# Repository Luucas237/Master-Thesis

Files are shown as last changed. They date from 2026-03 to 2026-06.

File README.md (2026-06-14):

**SSH Login:**
* Command: `ssh lukasgrab@raspberrypi.local`
* Password: `Rasbian1234`
* ip: `192.168.0.43`

```bash
xhost +local:root

docker run -it --rm --net=host --device /dev/snd -e DISPLAY=$DISPLAY -v /tmp/.X11-unix:/tmp/.X11-unix -v ~/Robotyka/Master-Thesis/Color_detection_ros_Ubuntu:/workspace -w /workspace master_pan_tilt_env bash

colcon build --packages-select pan_tilt_description --symlink-install

source install/setup.bash

ros2 run pan_tilt_description turret_gui.py
```

## ===== Launching =====
**Rasbian**
```bash
while true; do rpicam-vid -n -t 0 --width 640 --height 480 --framerate 30 --codec mjpeg --listen -o tcp://0.0.0.0:5000; sleep 1; done

rpicam-vid -t 0 --width 640 --height 480 --framerate 30 --codec mjpeg --inline -o udp://192.168.0.255:5000
```
**Rasbian ssh ubuntu**
```bash
cd /home/lukasgrab/Turret
libcamerify python3 tracker_guiless.py
python3 esp_test.py
python3 tracker.py
```
**Ubuntu**
```bash
mpv tcp://192.168.0.43:5000 --profile=low-latency --untimed --demuxer=lavf --demuxer-lavf-format=mjpeg
```

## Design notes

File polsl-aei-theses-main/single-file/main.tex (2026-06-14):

% !TeX spellcheck = pl_PL
%%%%%%%%%%%%%%%%%%%%%%%%%%%%%%%%%%%%%%%%%%%
%                                        %
% Szablon pracy dyplomowej magisterskiej %
% zgodny  z aktualnymi  przepisami  SZJK %
%                                        %
%%%%%%%%%%%%%%%%%%%%%%%%%%%%%%%%%%%%%%%%%%
%                                        %
%  (c) Krzysztof Simiński, 2018-2023     %
%                                        %
%%%%%%%%%%%%%%%%%%%%%%%%%%%%%%%%%%%%%%%%%%
%                                        %
% Najnowsza wersja szablonów jest        %
% podstępna pod adresem                  %
% github.com/ksiminski/polsl-aei-theses  %
%                                        %
%%%%%%%%%%%%%%%%%%%%%%%%%%%%%%%%%%%%%%%%%%
%
%
% Projekt LaTeXowy zapewnia odpowiednie formatowanie pracy,
% zgodnie z wymaganiami Systemu zapewniania jakości kształcenia.
% Proszę nie zmieniać ustawień formatowania (np. fontu,
% marginesów, wytłuszczeń, kursywy itd. ).
%
% Projekt można kompilować na kilka sposobów.
%
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
% brak kapitalizacji zywej paginy
\usepackage{fancyhdr}
\pagestyle{fancy}
\fancyhf{}
\fancyhead[LO]{\nouppercase{\it\rightmark}}
\fancyhead[RE]{\nouppercase{\it\leftmark}}
\fancyhead[LE,RO]{\it\thepage}

\fancypagestyle{tylkoNumeryStron}{%
   \fancyhf{} 
   \fancyhead[LE,RO]{\it\thepage}
}

\fancypagestyle{bezNumeracji}{%
   \fancyhf{} 
   \fancyhead[LE,RO]{}
}

\fancypagestyle{NumeryStronNazwyRozdzialow}{%
   \fancyhf{} 
   \fancyhead[LE]{\nouppercase{\autor}}
   \fancyhead[RO]{\nouppercase{\leftmark}} 
   \fancyfoot[CE, CO]{\thepage}
}

%%%%%%%%%%%%% OBCE WTRETY  
\newcommand{\obcy}[1]{\emph{#1}}
\newcommand{\english}[1]{{\selectlanguage{british}\obcy{#1}}}
%%%%%%%%%%%%%%%%%%%%%%%%%%%%%

% polskie oznaczenia funkcji matematycznych
\renewcommand{\tan}{\operatorname {tg}}
\renewcommand{\log}{\operatorname {lg}}

% jeszcze jakies drobiazgi

\newcounter{stronyPozaNumeracja}

%%%%%%%%%%%%%%%%%%%%%%%%%%% 
\newcommand{\printOpiekun}[1]{%		

    \StrLen{\Consultant}[\mystringlen]
    \ifthenelse{\mystringlen > 0}%
    {%
       {\large{\bfseries OPIEKUN, PROMOTOR POMOCNICZY}\par}
       
       {\large{\bfseries \Consultant}\par}
    }%
    {}
} 
%
%%%%%%%%%%%%%%%%%%%%%%%%%%%%%%%%%%%%%%%%%%%%%%
 
% Proszę nie modyfikować poniższych definicji!
\newcommand{\Author}{\FirstNameAuthor\ \MakeUppercase{\SurnameAuthor}} 
\newcommand{\Coauthor}{\FirstNameCoauthor\ \MakeUppercase{\SurnameCoauthor}}
\newcommand{\Type}{PRACA MAGISTERSKA}
\newcommand{\Faculty}{Wydział Automatyki, Elektroniki i Informatyki} 
\newcommand{\Polsl}{Politechnika Śląska}
\newcommand{\Logo}{politechnika_sl_logo_bw_pion_pl.pdf}
\newcommand{\LeftId}{Nr albumu}
\newcommand{\LeftProgram}{Kierunek}
\newcommand{\LeftSpecialisation}{Specjalność}
\newcommand{\LeftSUPERVISOR}{PROWADZĄCY PRACĘ}
\newcommand{\LeftDEPARTMENT}{KATEDRA}
%%%%%%%%%%%%%%%%%%%%%%%%%%%%%%%%%%%%%%%%%%%%%%

%%%%%%%%%%%%%%%%%%%%%%%%%%%%%%%%%%%%%%%%%%%%%%%
%                                             %
% KONIEC USTAWIEŃ                             %
%                                             %
%%%%%%%%%%%%%%%%%%%%%%%%%%%%%%%%%%%%%%%%%%%%%%%

%%%%%%%%%%%%%%%%%%%%%%%%%%%%%%%%%%%%%%%%%%%%%%%
%                                             %
% MOJE PAKIETY, USTAWIENIA ITD                %
%                                             %
%%%%%%%%%%%%%%%%%%%%%%%%%%%%%%%%%%%%%%%%%%%%%%%

% Tutaj proszę umieszczać swoje pakiety, makra, ustawienia itd.

%%%%%%%%%%%%%%%%%%%%%%%%%%%%%%%%%%%%%%%%%%%%%%%%%%%%%%%%%%%%%%%%%%%%%
% listingi i fragmentu kodu źródłowego 
% pakiet: listings lub minted
% % % % % % % % % % % % % % % % % % % % % % % % % % % % % % % % % % % 

% biblioteka listings
\usepackage{listings}
\lstset{%
morekeywords={string,exception,std,vector},% słowa kluczowe rozpoznawane przez pakiet listings
language=C++,% C, Matlab, Python, SQL, TeX, XML, bash, ... – vide https://www.ctan.org/pkg/listings
commentstyle=\textit,%
identifierstyle=\textsf,%
keywordstyle=\sffamily\bfseries, %\texttt, %
%captionpos=b,%
tabsize=3,%
frame=lines,%
numbers=left,%
numberstyle=\tiny,%
numbersep=5pt,%
breaklines=true,%
escapeinside={@*}{*@},%
}

% % % % % % % % % % % % % % % % % % % % % % % % % % % % % % % % % % % 
% pakiet minted
%\usepackage{minted}

% pakiet wymaga specjalnego kompilowania:
% pdflatex -shell-escape main.tex
% xelatex  -shell-escape main.tex

%\usepackage[chapter]{minted} % [section]
%%\usemintedstyle{bw}   % czarno-białe kody 
%
%\setminted % https://ctan.org/pkg/minted
%{
%%fontsize=\normalsize,%\footnotesize,
%%captionpos=b,%
%tabsize=3,%
%frame=lines,%
%framesep=2mm,
%numbers=left,%
%numbersep=5pt,%
%breaklines=true,%
%escapeinside=@@,%
%}

%%%%%%%%%%%%%%%%%%%%%%%%%%%%%%%%%%%%%%%%%%%%%%%%%%%%%%%%%%%%%%%%%%%%%

%%%%%%%%%%%%%%%%%%%%%%%%%%%%%%%%%%%%%%%%%%%%%%%
%                                             %
% KONIEC MOICH USTAWIEŃ                       %
%                                             %
%%%%%%%%%%%%%%%%%%%%%%%%%%%%%%%%%%%%%%%%%%%%%%%

%%%%%%%%%%%%%%%%%%%%%%%%%%%%%%%%%%%%%%%%

\begin{document}
%\kslistofremarks

\frontmatter

%%%%%%%%%%%%%%%%%%%%%%%%%%%%%%%%%%%%%%%%%%%%%%%
%                                             %
% PROSZĘ NIE MODYFIKOWAĆ STRONY TYTUŁOWEJ!    %
%                                             %
%%%%%%%%%%%%%%%%%%%%%%%%%%%%%%%%%%%%%%%%%%%%%%%

%%%%%%%%%%%%%%%%%%  STRONA TYTUŁOWA %%%%%%%%%%%%%%%%%%%
\pagestyle{empty}
{
	\newgeometry{top=1.5cm,%
	             bottom=2.5cm,%
	             left=3cm,
	             right=2.5cm}
 
	\ifxetex 
	  \begingroup
	  \setsansfont{Calibri}
	   
	\fi 
	 \sffamily
	\begin{center}
	

	{\Large\bfseries\Type\par}
	
	\vfill  \vfill  
			 
	{\large\Title\par}
	
	\vfill  
		
	{\large\bfseries\Author\par}
	
	{\normalsize\bfseries \LeftId: \IdAuthor}

	\printCoauthor
	
	\vfill  		
 
	{\large{\bfseries \LeftProgram:} \Program\par} 
	
	{\large{\bfseries \LeftSpecialisation:} \Specialisation\par} 
	 		
	\vfill  \vfill 	\vfill 	\vfill 	\vfill 	\vfill 	\vfill  
	 
	{\large{\bfseries \LeftSUPERVISOR}\par}
	
	{\large{\bfseries \Supervisor}\par}
				
	{\large{\bfseries \LeftDEPARTMENT\ \Departament} \par}
		
	{\large{\bfseries \Faculty}\par}
		
	\vfill  \vfill  

    \printOpiekun{\Consultant}
    
	\vfill  \vfill  
		
    {\large\bfseries  Gliwice \the\year}

   \end{center}	
       \ifxetex 
       	  \endgroup
       \fi
	\restoregeometry
}
  
%%%%%%%%%%%%%%%%%%%%%%%%%%%%%%%%%%%%%%%%%%%%%%%
%                                             %
% KONIEC STRONY TYTUŁOWEJ                     %
%                                             %
%%%%%%%%%%%%%%%%%%%%%%%%%%%%%%%%%%%%%%%%%%%%%%%  

\cleardoublepage

\rmfamily\normalfont
\pagestyle{empty}

%%% No to zaczynamy pisać pracę :-) %%%%

% TODO
\subsubsection*{Tytuł pracy} 
\Title

\subsubsection*{Streszczenie}

Przedmiotem niniejszej pracy magisterskiej jest projekt oraz wykonanie zrobotyzowanego demonstratora systemu kierowania niskomocowym laserem, zdolnego do automatycznego śledzenia poruszającego się celu na podstawie obrazu rejestrowanego przez kamerę cyfrową. Zasadniczą część badań stanowiła synteza i optymalizacja algorytmów sterowania nadążnego, umożliwiających precyzyjne utrzymanie wiązki optycznej na dedykowanym markerze. W pracy szczegółowo opisano architekturę rozproszoną zaprojektowanego systemu, obejmującą jednostkę nadrzędną do przetwarzania wizji (mikrokomputer Raspberry Pi) oraz warstwę wykonawczą realizującą wysterowanie silników krokowych (mikrokontroler ESP32). Dokonano komparatywnego zestawienia klasycznego algorytmu ciągłego (regulator PID strojony analitycznie metodą CHR oraz heurystycznie) z nieliniowym sterowaniem przekaźnikowym (regulator trójstawny \textit{Bang-Off-Bang}). Przedstawiono również proces parametryzacji układu oraz zaimplementowane techniki poprawy jakości i stabilności śledzenia, w tym dyskretny filtr Kalmana kompensujący zjawisko okluzji. Integralną część pracy stanowi obszerny zestaw badań laboratoryjnych oraz poligonowych (z wykorzystaniem drona), w których zweryfikowano algorytmy pod kątem precyzji naprowadzania (błąd średniokwadratowy, maksymalny uchyb dynamiczny) i kultury pracy mechaniki w zróżnicowanych warunkach i dystansach. Praca stanowi kompleksowe studium projektowania wieloosiowych, optoelektronicznych systemów śledzenia na wbudowanych platformach sprzętowych.

\subsubsection*{Słowa kluczowe} 
Laser niskomocowy, BSP, system śledzenia, PID, Trójpozycyjna regulacja.

\newpage
\subsubsection*{Thesis title} 
\begin{otherlanguage}{british}
\TitleAlt
\end{otherlanguage}

\subsubsection*{Abstract} 
\begin{otherlanguage}{british}
The subject of this Master's thesis is the design and implementation of a robotic demonstrator for a low-power laser targeting system, capable of automatically tracking a moving target based on images captured by a digital camera. The core of the research involved the synthesis and optimization of tracking control algorithms, enabling the precise maintenance of the optical beam on a dedicated marker. This thesis details the distributed architecture of the designed system, comprising a master unit for vision processing (a Raspberry Pi microcomputer) and an execution layer responsible for driving stepper motors (an ESP32 microcontroller). A comparative analysis was conducted between a classical continuous algorithm (a PID controller tuned analytically using the CHR method as well as heuristically) and nonlinear relay control (a three-position \textit{Bang-Off-Bang} controller). The parameterization process of the system was also presented, along with implemented techniques for improving tracking quality and stability, including a discrete Kalman filter compensating for the occlusion phenomenon. An integral part of the thesis consists of an extensive set of laboratory and field tests (involving a drone), wherein the algorithms were verified in terms of targeting precision (Root Mean Square Error, peak dynamic error) and the smoothness of mechanical operation across diverse conditions and distances. This thesis provides a comprehensive study on the design of multi-axis, optoelectronic tracking systems on embedded hardware platforms.

\end{otherlanguage}
\subsubsection*{Key words}  
\begin{otherlanguage}{british}
Low-power laser, UAV, tracking system, PID, Bang-off-bang regulation.
\end{otherlanguage}

%%%%%%%%%%%%%%%%%% SPIS TRESCI %%%%%%%%%%%%%%%%%%%%%%
% Add \thispagestyle{empty} to the toc file (main.toc), because \pagestyle{empty} doesn't work if the TOC has multiple pages
\addtocontents{toc}{\protect\thispagestyle{empty}}
\tableofcontents

%%%%%%%%%%%%%%%%%%%%%%%%%%%%%%%%%%%%%%%%%%%%%%%%%%%%%
\setcounter{stronyPozaNumeracja}{\value{page}}
\mainmatter
\pagestyle{empty}

\cleardoublepage

\pagestyle{NumeryStronNazwyRozdzialow}

%%%%%%%%%%%%%% wlasciwa tresc pracy %%%%%%%%%%%%%%%%%

% TODO
\chapter{Wstęp}

%\begin{itemize}
%\item wprowadzenie w problem/zagadnienie 
%\item osadzenie problemu w dziedzinie 
%\item cel pracy 
%\item zakres pracy 
%\item zwięzła charakterystyka rozdziałów 
%\end{itemize}

\section{Wprowadzenie do problematyki systemów antydronowych}

Współczesne środowisko bezpieczeństwa cywilnego oraz militarnego narażone jest na rosnące zagrożenia związane z rozwojem technologii bezzałogowych statków powietrznych. Zwiększająca się dostępność niewielkich i tanich dronów wpłynęła na wzrost przestępczości w kontekście naruszania prywatności oraz zakłócania funkcjonowania infrastruktury krytycznej. Dodatkowo, ostatnie lata pokazały, że mogą być one wykorzystywane jako precyzyjny środek rażenia celów wrażliwych w konfliktach zbrojnych. Niskobudżetowe modyfikacje komercyjnych dronów sprawiają, że są one realnym zagrożeniem dla obiektów o znacznie wyższej wartości.

W odpowiedzi na to wyzwanie testowane są systemy wykorzystujące wysokoenergetyczne wiązki laserowe, które postrzegane są jako optymalne rozwiązanie problemu asymetrii kosztów. W przeciwieństwie do konwencjonalnych systemów rakietowych czy artyleryjskich, gdzie koszt pojedynczego efektora może wynosić dziesiątki tysięcy dolarów, system laserowy oferuje możliwość oddania strzału za kwotę wynikającą jedynie z zużycia energii elektrycznej. Warto zaznaczyć, że wiązka lasera poruszająca się z prędkością światła eliminuje konieczność obliczania wyprzedzenia balistycznego, co teoretycznie upraszcza proces celowania. Jednakże implementacja napotyka na szereg barier inżynierskich m.in. odpowiednia regulacja mocy źródła promieniowania, optymalizacja detekcji w czasie rzeczywistym oraz mechaniczna precyzja układu kierowania wiązką. Ponadto należy mieć na uwadze, że ze względu na znacznie wyższą moc rażenia i wydłużony zasięg operacyjny współczesnych emiterów, jakakolwiek usterka sprzętowa lub błąd algorytmu niesie ze sobą krytyczne zagrożenie. Ewentualna utrata kontroli nad zrobotyzowaną głowicą nadążną może skutkować przypadkowym skierowaniem niszczącej wiązki na osoby postronne, co bezwzględnie wymusza implementację rygorystycznych, wielopoziomowych protokołów bezpieczeństwa.

Systemy klasy ATP, odpowiedzialne za akwizycję, śledzenie i wskazywanie celu, stanowią serce każdego urządzenia neutralizującego. Ich zadaniem jest utrzymanie skupionej plamki lasera na wrażliwym elemencie szybko poruszającego się obiektu przez czas niezbędny do jego termicznego uszkodzenia. O ile w systemach stacjonarnych dalekiego zasięgu problem ten rozwiązuje się poprzez masywne, stabilizowane żyroskopowo podstawy i kosztowne napędy bezpośrednie, o tyle w segmencie rozwiązań mobilnych i niskokosztowych wciąż brakuje skutecznych architektur. Niniejsza praca podejmuje próbę wypełnienia tej luki poprzez opracowanie zminiaturyzowanego systemu śledzącego, który integruje algorytmy przetwarzania obrazu w czasie rzeczywistym na niskobudżetowej platformie obliczeniowej wraz z możliwością działania na zewnętrznym źródle zasilania. Projekt ten ma na celu nie tylko demonstrację technologii, ale również zbadanie istotnych zagadnień inżynierskich m.in. opóźnienia w pętli sprzężenia zwrotnego, wpływ wybranych metod regulacji na stabilność układu czy mechaniczne aspekty przeniesienia napędu. Zwieńczeniem prac jest stworzenie funkcjonalnego prototypu, który posłuży jako baza do dalszych badań i rozwoju w dziedzinie systemów antydronowych.

% Współczesne środowisko bezpieczeństwa, podlega dynamicznym przemianom wymuszonym przez gwałtowny rozwój technologii bezzałogowych. Powszechna dostępność bezzałogowych statków powietrznych, potocznie określanych mianem dronów, doprowadziła do powstania nowych kategorii zagrożeń, z którymi tradycyjne systemy ochrony nie potrafią efektywnie rywalizować. Niewielkie, tanie i trudne do wykrycia platformy latające mogą być wykorzystywane nie tylko do naruszania prywatności czy zakłócania funkcjonowania infrastruktury krytycznej, takiej jak porty lotnicze, ale również jako precyzyjne środki rażenia w konfliktach. Obserwowane w ostatnich latach konflikty zbrojne jednoznacznie wykazały, że komercyjne drony, po niewielkich modyfikacjach, stają się skuteczną bronią, zdolną do unieszkodliwiania celów o wartości wielokrotnie przewyższającej koszt samego bezzałogowca. Zjawisko to zdefiniowało pilną potrzebę opracowania nowych metod neutralizacji, które byłyby ekonomicznie uzasadnione i technicznie skuteczne przeciwko masowym atakom małych obiektów latających.

% W odpowiedzi na to wyzwanie inżynieria systemów obronnych intensywnie rozwija koncepcję broni skierowanej energii. Systemy wykorzystujące wysokoenergetyczne wiązki laserowe postrzegane są jako optymalne rozwiązanie problemu asymetrii kosztów. W przeciwieństwie do konwencjonalnych systemów rakietowych czy artyleryjskich, gdzie koszt pojedynczego efektora może wynosić dziesiątki tysięcy dolarów, system laserowy oferuje możliwość oddania strzału za kwotę wynikającą jedynie z zużycia energii elektrycznej. Co więcej, wiązka lasera poruszająca się z prędkością światła eliminuje konieczność obliczania wyprzedzenia balistycznego, co teoretycznie upraszcza proces celowania. Jednakże praktyczna implementacja tej technologii napotyka na szereg barier inżynierskich, z których najpoważniejszą nie jest obecnie sama moc źródła promieniowania, lecz precyzja i szybkość działania systemu kierowania wiązką.

\section{Identyfikacja problemów badawczych}

Zadanie te wiąże się z koniecznością rozwiązania złożonych problemów interdyscyplinarnych, obejmujących mechanikę, optoelektronikę oraz informatykę. 

Pierwszym i kluczowym wyzwaniem jest opóźnienie w pętli sprzężenia zwrotnego układu sterowania. W systemach wizyjnych proces ten obejmuje akwizycję klatki obrazu, jej przesył do jednostki obliczeniowej, detekcję obiektu, wyznaczenie uchybu regulacji oraz wysterowanie napędów. Każdy z tych etapów wprowadza pewną zwłokę czasową. W przypadku śledzenia obiektów statycznych opóźnienie to jest pomijalne, jednak przy obiektach o wysokiej dynamice, takich jak drony wykonujące manewry unikowe, staje się ono przyczyną niestabilności układu. Liniowy sposób odczytu matrycy powoduje, że szybko poruszające się obiekty ulegają deformacjom geometrycznym, co drastycznie obniża skuteczność algorytmów detekcji opartych na uczeniu maszynowym.

Drugim istotnym problemem jest jakość układu mechanicznego napędu. Precyzyjne celowanie wymaga mechanizmu o wysokiej sztywności i zerowym luzie zwrotnym. Tradycyjne przekładnie zębate, powszechnie stosowane w serwomechanizmach modelarskich, charakteryzują się luzem technologicznym niezbędnym do ich pracy, który jednak przy zmianie kierunku obrotu powoduje chwilowy brak reakcji układu wyjściowego. W systemie śledzącym, który nieustannie koryguje położenie w osiach azymutu i elewacji, zjawisko to uniemożliwia płynne podążanie za celem, wprowadzając drgania mechaniczne przenoszone na wiązkę lasera. 

Trzecim aspektem jest interakcja promieniowania laserowego z materiałem celu. Większości systemów wzmacniane są włóknem węglowym jako głównym budulecem ram dronów i wykazują one specyficzne właściwości absorpcyjne. Istnieje zatem potrzeba zbadania efektywności źródeł promieniowania, które są w stanie wytworzyć wystarczającą ilość ciepła do uszkodzenia struktury kompozytowej.

\section{Cel i zakres pracy}

Głównym celem niniejszej pracy jest zaprojektowanie, wykonanie oraz weryfikacja eksperymentalna autonomicznego systemu mechatronicznego dwuosiowego, przeznaczonego do wykrywania, śledzenia i symulowanej neutralizacji dynamicznych celów powietrznych.

Zakres pracy obejmuje pełny proces inżynierski, począwszy od analizy teoretycznej, poprzez projektowanie CAD i dobór komponentów elektronicznych, aż po implementację oprogramowania i testy poligonowe. W warstwie mechanicznej praca koncentruje się na opracowaniu przekładni o uzębieniu strzałkowym mających na celu eliminację luzów zwrotnych. W warstwie informatycznej kluczowym elementem jest implementacja systemu wizyjnego bazującego na algorytmach segmentacji barw, wspieranych predykcyjną estymacją kinematyki obiektu za pomocą filtru Kalmana. Warstwa wykonawcza obejmuje integrację modułu lasera półprzewodnikowego dużej mocy oraz systemu bezpiecznego sterowania wiązką.

\section{Układ pracy}

Struktura niniejszej pracy przedstawia ewolucję zaprojektowanego systemu w kierunku realizacji postawionych celów orazetapy procesu badawczego.
Treść została podzielona na sześć zasadniczych rozdziałów.

Rozdział drugi stanowi przegląd literatury dotyczącej współczesnych metod śledzenia obiektów oraz teorii sterowania układami inercyjnymi. Zawiera również analizę dostępnych technologii laserowych w kontekście systemów celowniczych oraz ocenę ich skuteczności na podstawie doniesień naukowych.

Rozdział trzeci opisuje proces projektowania i budowy sprzętowej części demonstratora. Skoncentrowano się w nim na mechanice dwuosiowej platformy obrotowej. Przedstawiono tu również schemat architektury elektronicznej, bazującej na integracji platformy komputerowej Raspberry Pi z mikrokontrolerem ESP32 wraz z modułem laserowym i dystrybucją zasilania.

Rozdział czwarty poświęcony jest szczegółowemu opisowi zaimplementowanych algorytmów detekcji i przetwarzania obrazu. Omówiono w nim architekturę systemu wizyjnego i symulacyjnego opartego na ROS2. Opisano adaptację do dynamiki sceny, wykorzystując algorytmy detekcji ruchu na statycznym tle oraz progowanie w przestrzeni barw (HSV). W tej części pracy przedstawiono również matematyczny model filtru Kalmana, wdrożony w celu predykcji trajektorii celu i kompensacji chwilowej utraty widoczności.

Rozdział piąty koncentruje się na analizie dynamiki obiektu i syntezie praw sterowania. Przeprowadzono w nim identyfikację modelu kinematycznego na podstawie odpowiedzi skokowej w otwartej pętli, uwzględniając opóźnienia transportowe oraz inercję mechaniki. Główną część rozdziału stanowi analityczne strojenie dwóch układów sterowania: zoptymalizowanego regulatora trójstawnego (\textit{Bang-Off-Bang}) z wyliczoną strefą nieczułości oraz ciągłego regulatora proporcjonalno-różniczkującego, opartego na metodzie Chien-Hrones-Reswick.

Rozdział szósty prezentuje metodykę oraz wyniki badań eksperymentalnych zaprojektowanej głowicy nadążnej. Zawiera on kompleksowe porównanie obu zaimplementowanych algorytmów sterowania w odpowiedzi na wymuszenia skokowe, krzywoliniowe oraz podczas dynamicznej zmiany odległości. Przedstawiono w nim również ocenę skuteczności demonstratora w trudnych warunkach polowych podczas śledzenia poruszającego się bezzałogowego statku powietrznego.

Pracę zamyka podsumowanie, w którym zawarto krytyczną ocenę stopnia realizacji postawionych celów, omówiono napotkane trudności sprzętowo-środowiskowe oraz sformułowano szczegółowe rekomendacje i perspektywy dalszego rozwoju zrobotyzowanych systemów obronnych.

% TODO
\chapter{Analiza tematu}  % Analiza tematu
% 

%\begin{itemize}
%\item Jaki problem chcę (muszę :-) rozwiązać?
%\item Dlaczego rozwiązanie problemu jest ważne?
%\item Jak inni rozwiązują ten problem?
%\item Jakie są zalety i wady tych rozwiązań?
%\end{itemize}

\section{Specyfika procesu neutralizacji kinetycznej i energetycznej}

Zadanie polegające na wykryciu, śledzeniu i neutralizacji niewielkiego, szybko poruszającego się obiektu w przestrzeni powietrznej stanowi złożone wyzwanie. Cel, taki jak dron wyścigowy FPV czy amunicja krążąca, charakteryzuje się wysoką dynamiką zmian wektora prędkości, co w połączeniu z nieprzewidywalnymi zakłóceniami zewnętrznymi, wymaga od układu sterowania reakcji w czasie zbliżonym do rzeczywistego.

Istotą problemu jest zamknięcie pętli sprzężenia zwrotnego w układzie wizyjnym. Proces ten składa się z sekwencji zdarzeń obejmującej akwizycję fotonów przez matrycę światłoczułą, cyfrowy odczyt i transmisję danych, algorytmiczną detekcję obiektu, estymację błędu położenia oraz mechaniczną reakcję napędu. Sumaryczny czas trwania tych operacji definiuje opóźnienie systemowe. W systemach śledzących, opóźnienie to wprowadza przesunięcie fazowe w sygnale sterującym. W praktyce oznacza to, że jeśli system reaguje zbyt wolno w stosunku do prędkości kątowej celu, wiązka lasera nie tylko nie trafi w obiekt, ale cały układ mechaniczny może wpaść w oscylacje o narastającej amplitudzie. Wyzwanie to jest potęgowane przez konieczność utrzymania skupionej plamki lasera na powierzchni celu przez czas niezbędny do przekazania niszczącej dawki energii termicznej.

\newpage

\section{Przegląd dostępnych rozwiązań i ich ograniczenia}

Analiza rynku systemów antydronowych pozwala na wyodrębnienie dwóch skrajnych podejść do rozwiązania problemu śledzenia, z których żadne nie spełnia w pełni założeń projektowych dla taniego i mobilnego systemu ochrony.

Pierwszą grupę stanowią profesjonalne systemy militarne klasy CIWS (ang. \textit{Close-In Weapon Systems}). Rozwiązania te wykorzystują aktywne radary śledzące oraz głowice optoelektroniczne. Napęd realizowany jest zazwyczaj poprzez silniki momentowe w układzie bezpośrednim, co eliminuje luzy mechaniczne i zapewnia dynamikę niezbędną do śledzenia obiektów naddźwiękowych. Mimo wysokiej skuteczności, bariera kosztowa oraz masa własna tych urządzeń wykluczają ich powszechne zastosowanie do ochrony infrastruktury cywilnej czy wykorzystanie w systemach przenośnych.

Na przeciwległym biegunie znajdują się rozwiązania amatorskie i półprofesjonalne, bazujące na podzespołach modelarskich. Konstrukcje te wykorzystują zazwyczaj serwomechanizmy sterowane sygnałem PWM oraz tanie kamery internetowe lub przemysłowe standardu USB. Głównym ograniczeniem tych systemów jest niska sztywność mechaniczna oraz obecność znaczących luzów w przekładniach zębatych serwomechanizmów. Luz zwrotny powoduje powstanie strefy nieczułości przy zmianie kierunku obrotu głowicy, co uniemożliwia precyzyjne mikrokorekty położenia wiązki lasera. Ponadto, budżetowe systemy wizyjne w przeważającej większości korzystają z sensorów CMOS wyposażonych w migawkę postępującą. Przy dużej prędkości obrotowej głowicy, liniowy sposób odczytu matrycy powoduje geometryczne zniekształcenia obrazu, co wprowadza błędne dane do algorytmów predykcji ruchu i często prowadzi do całkowitej rozbieżności modelu śledzenia.

\section{Zidentyfikowane bariery technologiczne}

Pierwszą barierą jest problem mechaniczny związany z precyzją przekładni. Wymóg niskiego kosztu i małej masy sugeruje wykorzystanie technologii druku 3D, jednak standardowe tworzywa termoplastyczne charakteryzują się mniejszą sztywnością niż metal. Konieczne jest zatem zaprojektowanie takiej geometrii uzębienia, która zapewni samocentrowanie układu, minimalizację luzów oraz równomierny rozkład naprężeń, co jest trudne do osiągnięcia przy użyciu typowych zębów prostych.

Drugą barierą jest wydajność obliczeniowa w kontekście opóźnień. Zastosowanie zaawansowanych sieci neuronowych do detekcji dronów na platformach wbudowanych wiąże się ze znacznym obciążeniem procesora i spadkiem liczby klatek na sekundę. Wymaga to implementacji hybrydowych algorytmów sterowania, które potrafią estymować pozycję celu w chwilach braku nowych danych wizyjnych.

Trzecią barierą jest efektywność energetyczna procesu neutralizacji. Typowe dla dronów komercyjnych materiały konstrukcyjne, takie jak polimery wzmacniane włóknem węglowym, wykazują zróżnicowaną absorpcję promieniowania. Wykorzystanie standardowych laserów często wymaga stosowania wysokich mocy, co komplikuje układ zasilania i chłodzenia. 

Poniższa analiza literatury szczegółowo omawia stan wiedzy w zakresie metod kompensacji tych ograniczeń, stanowiąc teoretyczną podbudowę dla rozwiązań zaproponowanych w dalszej części pracy.

%%%%%%%%%%%%%%%% LITERATURA %%%%%%%%%%%%%%%%
\section{Analiza literatury}

\subsection{Metody śledzenia obiektów}

W pracy Li i in. \cite{bib:Li2025} przeprowadzono szczegółową analizę wpływu sprzężenia zwrotnego z obrazu na dynamikę systemu \textbf{ATP (Acquisition, Tracking, Pointing)}. System tego typu można traktować jako układ serwomechanizmu, w którym sterowanie odbywa się na podstawie sygnału z kamery. W literaturze wyróżnia się dwa główne problemy ograniczające możliwości precyzyjnego śledzenia. Pierwszym z nich jest \textbf{opóźnienie obrazu} (np. rzędu 30~ms), które powoduje przesunięcie fazowe i zmniejszenie marginesu stabilności układu, co w praktyce ogranicza maksymalną prędkość kątową celu możliwą do śledzenia. Drugim ograniczeniem jest \textbf{niska częstotliwość próbkowania obrazu} (np. 50~Hz). Z uwagi na długi czas pomiędzy kolejnymi klatkami układ okresowo nie posiada aktualnej informacji o położeniu obiektu, co sprzyja powstawaniu oscylacji i drgań.

Aby rozwiązać te problemy, autorzy zastosowali \textbf{wieloczęstotliwościowy regulator feedforward}, który pozwala zsynchronizować wolne sprzężenie zwrotne z kamery z szybkim torem sterowania napędami. W praktyce oznacza to, że pętla napędów operuje z częstotliwością 5000~Hz, podczas gdy obraz uaktualnia pozycję celu co 20~ms. Rozwiązanie to uzupełniono o predykcję trajektorii celu, estymującą położenie obiektu pomiędzy klatkami na podstawie jego aktualnej prędkości i przyspieszenia. Co więcej, wdrożono sterowanie typu model-free, dzięki któremu regulator nie opiera się na dokładnym modelu matematycznym platformy, co ułatwia przenoszenie algorytmu pomiędzy różnymi konfiguracjami sprzętowymi bez żmudnej identyfikacji parametrów.

Z matematycznego punktu widzenia, opóźnienie toru obrazu $T_{d}$ wprowadza w dziedzinie Laplace’a czynnik $e^{-sT_{d}}$, który wykorzystując aproksymację Padé rzędu pierwszego, można zapisać jako:
\begin{equation}
e^{-sT_{d}} \approx \frac{1 - \frac{sT_{d}}{2}}{1 + \frac{sT_{d}}{2}}.
\end{equation}
Obecność opóźnienia generuje dodatkowe zera i bieguny w transmitancji układu, co znacząco obniża margines fazy. Ponadto, ze względu na częstotliwość próbkowania $f_{s}$ i czas pomiędzy próbkami $T_{s}$, aktualizacja położenia odbywa się skokowo ($y[k] = \theta(kT_{s} - T_{d})$). Przeprowadzona przez badaczy analiza częstotliwościowa wykazała, że wzrost opóźnienia oraz spadek częstotliwości próbkowania pogarszają zdolność śledzenia manewrującego celu. W skrajnych przypadkach (np. $T_{d} = 30$~ms, $f_{s} = 50$~Hz) system całkowicie traci stabilność już przy prędkościach kątowych rzędu 90$^\circ$/s. Do kompensacji tych zjawisk obok sterowania wieloczęstotliwościowego stosuje się również filtry predykcji zredukowanego rzędu.

Pod względem sprzętowym typowy system ATP składa się z podsystemu obrazowania (kamera CCD/CMOS), dwuosiowej konstrukcji napędzanej silnikami BLDC z enkoderami wysokiej rozdzielczości, sterownika niskopoziomowego oraz modułu obliczeniowego. W testach laboratoryjnych wykorzystano tło eksperymentalne z obrotową tarczą, a jako wskaźnik śledzący posłużył laser niskomocowy. Weryfikacja praktyczna objęła cele poruszające się z prędkością kątową do 90$^\circ$/s oraz przyspieszeniem do 470$^\circ$/s$^2$. Zastosowany algorytm predykcyjny i wieloczęstotliwościowy pozwolił na zwiększenie dokładności śledzenia o 70--89,9\% w stosunku do systemu bez kompensacji, znacznie redukując ryzyko utraty celu przy gwałtownych manewrach.

\subsection{Hybrydowa detekcja obiektów w systemach o statycznym tle}

W nawiązaniu do problematyki opóźnień w pętli sprzężenia zwrotnego wymagającym wyzwaniem staje się minimalizacja czasu przetwarzania pojedynczej klatki obrazu. W klasycznym podejściu, wykorzystującym głębokie sieci neuronowe na pełnej rozdzielczości sensora, narzut obliczeniowy jest znaczny, co bezpośrednio przekłada się na degradację marginesu stabilności systemu śledzenia. Alternatywą dla tego rozwiązania, szczególnie efektywną w systemach stacjonarnych ochrony obiektów, jest zastosowanie \textbf{dwuetapowej kaskady detekcyjnej}, którą szczegółowo przeanalizowali Seidaliyeva i współpracownicy \cite{bib:Seidaliyeva2020}.

Autorzy ci zaproponowali architekturę systemu detekcji, która integruje metody przetwarzania obrazu z lekkimi sieciami neuronowymi w celu osiągnięcia działania w czasie rzeczywistym. Fundamentalnym założeniem tej metody jest statyczność obserwowanej sceny, co pozwala na wykorzystanie algorytmów odejmowania tła do wstępnej selekcji obszarów zainteresowania. Proces ten rozpoczyna się od konwersji obrazu do skali szarości oraz filtracji szumów przetwornika, po czym następuje detekcja ruchu przy użyciu algorytmu mieszaniny rozkładów Gaussa (MOG2). Pozwala to na skuteczne odseparowanie obiektów pierwszoplanowych od statycznego otoczenia, nawet przy zmiennych warunkach oświetleniowych.

W kolejnym etapie, na wygenerowanej masce binarnej przeprowadzane są operacje morfologiczne dylatacji i erozji, mające na celu zamknięcie luk w wykrytych sylwetkach oraz eliminację drobnych artefaktów. Dopiero tak wyodrębnione fragmenty obrazu (ang. \textit{Regions of Interest}, ROI), zawierające potencjalny cel, są przekazywane do klasyfikatora opartego na sieci neuronowej. Główną zaletą tego podejścia jest drastyczna redukcja przestrzeni poszukiwań dla sieci głębokiej. Zamiast analizować piksele pełnej klatki, algorytm klasyfikuje jedynie niewielkie wycinki, co pozwala na utrzymanie wysokiej częstotliwości odświeżania pętli sterowania i precyzyjne odróżnienie dronów od innych obiektów ruchomych, takich jak ptaki, przy minimalnym obciążeniu jednostki obliczeniowej.

Należy jednak podkreślić, że omawiana metoda bazująca na statycznym tle posiada istotne ograniczenie w kontekście systemów wyposażonych w głowice obrotowe. Ruch kamery podczas skanowania przestrzeni powoduje globalną zmianę wartości pikseli, co przez algorytmy klasy MOG2 interpretowane jest jako ruch całego otoczenia, generując lawinowo fałszywe detekcje. Z tego względu, w praktycznych aplikacjach obronnych, podsystem wizyjny powinien współpracować z zewnętrznym sensorem nadrzędnym, takim jak radar lub detektor akustyczny. W takiej konfiguracji sensor nadrzędny wstępnie wyznacza azymut celu, wymuszając obrót platformy do zadanego sektora, a algorytm wizyjny aktywowany jest dopiero po zatrzymaniu i ustabilizowaniu głowicy, przejmując zadanie precyzyjnego celowania i identyfikacji.

\subsection*{Rola filtru Kalmana w stabilizacji śledzenia i fuzji danych wizyjnych}

W systemach śledzenia obiektów dynamicznych poleganie na surowych danych z detektora wizyjnego jest niewystarczające ze względu na występujący szum pomiarowy, opóźnienia przetwarzania oraz okresowe zaniki detekcji spowodowane zasłonięciem celu lub rozmyciem obrazu. Analiza najnowszej literatury przedmiotu wskazuje, że filtr Kalmana przestał pełnić w nowoczesnych systemach funkcję jedynie wygładzania trajektorii, stając się kluczowym elementem aktywnie wspierającym i sterującym procesem detekcji wizyjnej.

Istotę predykcyjnego wykorzystania filtru w śledzeniu małych obiektów latających opisali Son i inni w pracy poświęconej śledzeniu mikrodronów \cite{bib:Son2021}. Badacze ci zwracają uwagę na problem gubienia celu przez klasyczne algorytmy wizyjne w momentach gwałtownych zmian oświetlenia lub wystąpienia rozmycia ruchu, co jest zjawiskiem powszechnym przy szybkim przemieszczaniu się kamery. W zaproponowanym przez nich rozwiązaniu filtr Kalmana pełni rolę nadrzędnego predyktora modelującego stan obiektu jako wektor zawierający pozycję oraz prędkość. W sytuacji gdy algorytmy wizyjne oparte na przepływie optycznym lub histogramach zawiodą i nie zwrócą poprawnego regionu zainteresowania, system płynnie przełącza się na estymację wynikającą z modelu kinematycznego. Dzięki temu, nawet przy chwilowym braku kontaktu wzrokowego z celem, mechanizm wykonawczy może kontynuować ruch zgodnie z przewidywanym wektorem prędkości. Takie podejście drastycznie zwiększa szansę na ponowne uchwycenie celu w momencie ustania zakłóceń, co potwierdzono eksperymentalnie dla obiektów o wysokiej dynamice.

Jeszcze bardziej zaawansowane podejście do integracji filtru z systemem wizyjnym zaprezentowali Abdelkader i współpracownicy w systemie o nazwie SMART-TRACK \cite{bib:Abdelkader2025}. Autorzy ci adresują problem różnicy częstotliwości pracy poszczególnych podsystemów. Podczas gdy precyzyjne detektory oparte na głębokich sieciach neuronowych pracują ze stosunkowo niską częstotliwością rzędu kilkudziesięciu herców, pętla sterowania serwomechanizmów wymaga odświeżania na poziomie co najmniej stu herców. W rozwiązaniu tym stan estymowany przez filtr Kalmana nie jest jedynie wynikiem końcowym, lecz służy do aktywnego zawężania przestrzeni poszukiwań dla detektora wizyjnego. Wykorzystując macierz kowariancji błędu, algorytm wyznacza stochastyczny obszar niepewności wokół przewidywanej pozycji celu. W kolejnym kroku czasowym detektor wizyjny nie musi analizować pełnej klatki obrazu, lecz skupia się jedynie na wyznaczonym dynamicznie fragmencie. Strategia ta pozwala na znaczną oszczędność mocy obliczeniowej oraz utrzymanie ciągłości śledzenia w czasie rzeczywistym poprzez wypełnianie luk czasowych między rzadkimi pomiarami z sieci neuronowej wysokoczęstotliwościowymi predykcjami stanu.

W kontekście projektowanego systemu implementacja filtru Kalmana pozwala zatem na realizację dwóch kluczowych funkcji. Po pierwsze umożliwia kompensację opóźnień poprzez estymację pozycji celu w przyszłej chwili czasu, co pozwala na wycelowanie wiązki w punkt wyprzedzenia zamiast w historyczną pozycję obiektu. Po drugie zapewnia odporność układu na chwilowe błędy detekcji wynikające ze specyfiki sensora wizyjnego, utrzymując płynność ruchu głowicy w sytuacjach krytycznych.
%%%%%%%%%%%%%%%%%%%%%%%%%%%%%%

\subsection{Ograniczenia sterowania skokowego w układach o wysokiej dynamice}

W literaturze badającej układy o nieliniowej charakterystyce i dużej manewrowości często rozważa się implementację regulatorów skokowych (np. \textit{bang-bang} lub \textit{bang-off-bang}) z uwagi na ich teoretyczną optymalność czasową przy minimalizacji czasu dojścia do zadanej pozycji. Należy jednak krytycznie ocenić ich przydatność w wewnętrznych pętlach sterowania, które wymagają najwyższej precyzji działania. Przykładem dogłębnej analizy tego problemu są badania nad zwinnością samolotów myśliwskich, w których modelowano nieliniową dynamikę w stanach gwałtownych manewrów \cite{bib:caferov2019building}. Autorzy wykazali, że bezpośrednie zastosowanie klasycznego, dwupołożeniowego regulatora \textit{bang-bang} do kontroli wewnętrznej tak dynamicznego obiektu jest nieodpowiednie i ustępuje miejsca wielowymiarowym, ciągłym algorytmom sterowania \cite{bib:caferov2019building}.

W systemach mechatronicznych naturalnym rozwinięciem tego podejścia jest wprowadzenie strefy nieczułości (ang. \textit{deadband}), tworzące układ trójpołożeniowy (tzw. \textit{bang-off-bang}). Rozwiązanie to łagodzi problem ciągłych oscylacji wokół punktu pracy, jednak mechanika obiektu wciąż jest poddawana skokowemu wymuszaniu pełną mocą w momencie opuszczenia strefy nieczułości. Z punktu widzenia precyzyjnych systemów nadążnych typu PAN/TILT, powstawanie gwałtownych skoków sygnału sterującego wywołuje w mechanice zjawisko szarpania i wibracji o wysokiej częstotliwości. 

Nawet w inżynierii kosmicznej, gdzie napędy korekcyjne tzw. pędniki, mają natywną charakterystykę skokową, odchodzi się od prostych algorytmów przełączających. Współczesne trendy polegają na zastępowaniu ich zaawansowanym sterowaniem predykcyjnym, co pozwala optymalizować momenty załączeń i minimalizować zużycie energii podczas precyzyjnych manewrów, takich jak dokowanie \cite{bib:VirgiliLlop2017}. W układach zintegrowanych z modułami wizyjnymi, skokowa praca napędów prowadzi do wibracji samej osi optycznej, co drastycznie degraduje jakość pozyskiwanego strumienia wideo i uniemożliwia stabilne śledzenie. Z tego powodu, w budowie układów celowniczych poszukuje się alternatyw na rzecz ciągłych algorytmów regulacji np. PID.

\subsection{Wykorzystanie środowisk symulacyjnych w projektowaniu systemów wizyjnych}

Ze względu na złożoność strojenia algorytmów regulacji, które są bezpośrednio sprzężone z analizą obrazu cyfrowego, nowoczesna metodyka inżynierska zakłada przeniesienie początkowej fazy testów do sfery wirtualnej. Jak udowadniają Virgili-Llop i in. (2017) na przykładzie algorytmów dokowania statków kosmicznych, eksperymentalna weryfikacja krytycznych systemów sterowania bezwzględnie wymaga stworzenia dedykowanych stanowisk testowych lub zaawansowanych symulacji przed wdrożeniem na docelowym obiekcie \cite{bib:VirgiliLlop2017}. 

W robotyce naziemnej funkcję tę doskonale spełniają silniki fizyki. Clark (2005) z powodzeniem wykorzystał środowisko Gazebo do walidacji hybrydowych algorytmów sterowania mobilnymi robotami śledzącymi przed ich fizyczną implementacją \cite{bib:Clark2005}. Zastosowanie zaawansowanego środowiska wirtualnego pozwala na bezpieczne modelowanie charakterystyk sensorów wizyjnych oraz obserwację zachowania mechaniki układu w odpowiedzi na wyliczany uchyb. Co szczególnie istotne, praca w symulatorze umożliwia testowanie obiektu w skrajnych warunkach operacyjnych bez ryzyka sprzętowego uszkodzenia kosztownych podzespołów elektroniki oraz przekładni mechanicznych w wyniku oscylacji. To bezpieczne środowisko testowe tworzy idealny fundament do zaimplementowania zautomatyzowanego strojenia nastaw regulatora PID.

\subsection{Właściwości kamer o matrycy z jednoczesną ekspozycją w systemach percepcji robotów}

Aktualnie wykorzystywane systemy wizyjne dedykowane do analizy zjawisk dynamicznych wymagają sensorów o specyficznej architekturze, zdolnych do eliminacji zniekształceń geometrycznych powstających podczas rejestracji ruchu. Podstawową cechą odróżniającą kamery z migawką globalną (ang. \textit{global shutter}) od rozwiązań standardowych jest sposób naświetlania matrycy. W technologii tej proces akumulacji ładunku elektrycznego rozpoczyna się i kończy w tym samym momencie dla wszystkich pikseli sensora, co pozwala na wierne zamrożenie ruchu bez artefaktów czasowych charakterystycznych dla migawki postępującej (ang. \textit{rolling shutter}).

Implementacja tego mechanizmu wiąże się jednak ze znacznym skomplikowaniem struktury półprzewodnikowej pojedynczego piksela. Jak wykazują badania przeprowadzone przez Lauxtermanna i współpracowników, standardowa architektura czterotranzystorowa, powszechnie stosowana w sensorach konsumenckich ze względu na wysoką czułość i niski poziom szumów, okazuje się niewystarczająca dla trybu migawki globalnej. Fizycznym ograniczeniem jest w tym przypadku konieczność jednoczesnego przechowywania ładunku ze wszystkich pikseli przed ich sekwencyjnym odczytem. Wymaga to rozbudowy układu o dodatkowe elementy pamięciowe wewnątrz każdego piksela, co prowadzi do zmniejszenia współczynnika wypełnienia i potencjalnego spadku czułości \cite{bib:LauxtermannGlobalShutter}.

\subsection*{Analiza porównawcza i wpływ typu migawki na algorytmy sterowania}

Analiza literatury przedmiotu wskazuje na istotny kompromis pomiędzy jakością odwzorowania ruchu a parametrami szumowymi i kosztem implementacji sensorów z migawką globalną. Lauxtermann, Lee, Stevens i Joshi dowodzą, że osiągnięcie wysokiej jakości obrazu w technologii \textit{Global Shutter} wymaga zastosowania zaawansowanych architektur, np. układów siedmiotranzystorowych z przypiętą fotodiodą, które pozwalają zredukować szum odczytu, lecz są podatne na zjawisko przecieku migawki. Z kolei Tandi i in. podkreślają, że mimo wyższych kosztów, sensory te stanowią niezbędne źródło referencyjne w systemach wymagających precyzji geometrycznej, której nie są w stanie zapewnić tańsze sensory z migawką postępującą bez skomplikowanego przetwarzania obliczeniowego \cite{bib:Tandi2025, bib:LauxtermannGlobalShutter}.

\newpage

Dobór sensora ma krytyczne znaczenie dla stabilności pętli sterowania opartej na wizji maszynowej, szczególnie w systemach wykorzystujących estymację stanu, takich jak filtr Kalmana. W początkowej fazie przetwarzania, opartej na segmentacji barwnej i wyznaczaniu centroidu obiektu (np. piłki), zniekształcenia geometryczne wprowadzane przez migawkę postępującą, powodują systematyczny błąd pomiaru pozycji, zależny od prędkości obiektu. Błąd ten, interpretowany przez predyktor Kalmana jako rzeczywista zmiana dynamiki ruchu, może prowadzić do oscylacji układu celującego i utraty śledzonego celu. Zastosowanie kamery \textit{Global Shutter} eliminuje ten problem u źródła, dostarczając pomiary zgodne z rzeczywistą geometrią sceny w danej chwili czasowej.

Zasadność użycia tej technologii potwierdzają również badania nad skutecznością głębokich sieci neuronowych, których implementacja jest przewidziana w dalszych etapach rozwoju systemu. Kemeshi i współpracownicy przeprowadzili eksperyment porównawczy na mobilnej platformie robotycznej, badając wpływ typu migawki na skuteczność modelu detekcji YOLOv8. Wyniki wykazały, że przy identycznych warunkach dynamicznych, kamera z migawką globalną (AR0234) osiągnęła średnią dokładność detekcji na poziomie 84,7\%, podczas gdy dla kamery z migawką postępującą (IMX462) skuteczność spadła do 70,1\%. Autorzy wskazują, że deformacje kształtu obiektów w ruchu, charakterystyczne dla sensorów \textit{rolling shutter}, utrudniają ekstrakcję cech przez warstwy konwolucyjne sieci, co skutkuje znaczącym spadkiem efektywności detekcji. Wnioski te jednoznacznie przemawiają za wyborem sensora \textit{Global Shutter} jako rozwiązania zapewniającego integralność danych zarówno dla klasycznych algorytmów estymacji, jak i zaawansowanych metod sztucznej inteligencji \cite{bib:Kemeshi2024}.

%%%%%%%%%%%%%%%%%%%%%%%%%%%%
\subsection{Cechy fizyczne dronów}
\subsection*{Analiza materiałowa wirników quadrocopterów}

W pracy \cite{bib:tiruvenkadam2024} przeprowadzono badania dotyczące doboru materiałów stosowanych w konstrukcji wirników dronów oraz ich wpływu na właściwości eksploatacyjne całego układu. W szczególności analizie poddano tworzywa polimerowe, takie jak poliwęglan (PC) i akrylonitryl-butadien-styren (ABS), a także kompozyty zbrojone włóknem węglowym (CFRP). Autorzy wykazali, że dobór materiału determinuje nie tylko wytrzymałość mechaniczną elementu, ale również jego odporność termiczną i podatność na deformacje, co bezpośrednio przekłada się na stabilność lotu.

Poliwęglan charakteryzuje się wytrzymałością na rozciąganie rzędu 55--70~MPa, modułem Younga w zakresie 2,2--2,4~GPa oraz wysoką odpornością na uderzenia. Dzięki tym właściwościom PC zapewnia dobrą sprężystość i zdolność do absorbowania energii przy nagłych obciążeniach. Ważnym parametrem jest także odporność termiczna (HDT), wynosząca około 115--125$^\circ$C. Z kolei ABS wykazuje niższą wytrzymałość na rozciąganie (35--50~MPa) oraz zbliżony moduł sprężystości (ok. 2~GPa), jednak jego odporność udarowa i stabilność termiczna (90--100$^\circ$C) są słabsze niż w przypadku poliwęglanu. Najlepsze parametry uzyskano dla kompozytów CFRP, których wytrzymałość na rozciąganie przekracza 500~MPa, a moduł Younga mieści się w przedziale 70--200~GPa. Co więcej, odporność temperaturowa tych materiałów znacznie przewyższa tworzywa polimerowe i może sięgać ponad 200$^\circ$C, w zależności od użytej matrycy epoksydowej. CFRP zapewnia również najwyższy stosunek sztywności do masy, co czyni go materiałem preferowanym w konstrukcjach profesjonalnych i wyczynowych.

W badaniach podkreślono, że kluczowym problemem eksploatacyjnym wirników jest ich podatność na deformacje spowodowane obciążeniami mechanicznymi lub podwyższoną temperaturą. Nawet niewielkie odkształcenia geometryczne mogą istotnie zmienić profil aerodynamiczny łopaty. Prowadzi to do spadku współczynnika siły nośnej, zwiększenia oporu oraz pojawienia się asymetrii pomiędzy poszczególnymi wirnikami. W efekcie mogą wystąpić dodatkowe momenty przechylające, powodujące wibracje konstrukcji, utratę stabilności oraz nadmierne obciążenie układu sterowania. W skrajnych przypadkach dron może wejść w niekontrolowane oscylacje lub całkowicie utracić zdolność utrzymania zadanej trajektorii. W praktyce oznacza to, że właściwości materiałowe wirników są krytyczne nie tylko dla trwałości elementów, ale również dla jakości całego systemu sterowania lotem.

%%%%%%%%%%%%%%%%%%%%%
\subsection{Lasery niskomocowe}

\subsection*{Badania nad absorpcją energii lasera diodowego w różnych materiałach}

W pracy \cite{bib:pantsar2004} przedstawiono szczegółowe badania nad absorpcją energii wiązki lasera diodowego o mocy 3~kW w powierzchniach stalowych poddanych różnym przygotowaniom. Zastosowany laser pracował w trybie ciągłym z długością fali $\lambda = 940$~nm, typową dla przemysłowych laserów diodowych wykorzystywanych w procesach obróbki cieplnej. W układzie optycznym średnica ogniska wynosiła około 13~mm, a gęstość mocy dochodziła do 22~kW/cm$^2$.

W badaniach oceniano absorpcję powierzchniową, definiowaną jako stosunek energii pochłoniętej do energii dostarczonej. Testy przeprowadzono dla kilku wariantów przygotowania próbek stalowych:
\begin{enumerate}
    \item \textbf{Stal w stanie surowym (po obróbce skrawaniem)} - absorpcja mieściła się w zakresie 46--72\%, w zależności od czasu ekspozycji.
    \item \textbf{Stal po piaskowaniu tlenkiem glinu} - dzięki zwiększonej chropowatości i powstaniu warstwy tlenków, absorpcja wzrosła do wartości 66--81\%.
    \item \textbf{Stal pokryta warstwą grafitu} - zastosowanie powłoki znacząco podniosło zdolność pochłaniania energii, osiągając poziom powyżej 85\%.
\end{enumerate}

Czas oddziaływania wiązki laserowej był zmienny i wynosił od kilkuset milisekund do kilku sekund, co pozwalało na obserwację efektów cieplnych przy różnym czasie dostarczania energii. Wykazano, że krótszy czas ekspozycji przy tej samej energii skutkuje osiąganiem wyższych temperatur powierzchni, co związane jest z mniejszym rozpraszaniem ciepła do otoczenia. Z kolei dłuższe naświetlanie prowadziło do stabilizacji temperatury, lecz przy niższej wartości maksymalnej. W badaniach zarejestrowano, że powierzchnie stalowe mogły osiągać temperatury rzędu kilkuset stopni Celsjusza, co wystarczało do inicjacji procesów utleniania i lokalnych zmian strukturalnych.

Odległość pomiędzy układem optycznym a próbką była utrzymywana na poziomie około 30~cm, przy czym układ ogniskujący zapewniał stałą średnicę plamki na powierzchni materiału. W ten sposób możliwe było uzyskanie powtarzalnych warunków eksperymentu i porównanie wpływu rodzaju powierzchni na absorpcję.

Wyniki badań jednoznacznie pokazały, że zastosowanie warstw absorbujących, takich jak grafit, znacząco zwiększa efektywność nagrzewania wiązką laserową. W praktyce oznacza to, że procesy obróbki cieplnej, hartowania czy teoretyczne oddziaływanie lasera na cele ruchome mogą być zoptymalizowane poprzez modyfikację powierzchni obiektu, co prowadzi do efektywniejszego wykorzystania energii wiązki.

%%%%%%%%%%%%%%

\subsection*{Charakterystyka lasera i efektywność obróbki CFRP}

W badaniach zastosowano laser włóknowy domieszkowany iterbem (Yb-fiber laser) firmy Furukawa Electric o długości fali $\lambda = 1084$~nm \cite{bib:niino2016laser}. Źródło pracowało w trybie ciągłym oraz quasi-ciągłym, przy średniej mocy w zakresie $2{-}3$~kW oraz średnicy rdzenia światłowodu wynoszącej 50~$\mu$m. Wiązka była skupiana przy pomocy soczewki typu f-theta (ogniskowa $f=306$~mm) i prowadzona po powierzchni materiału przy użyciu skanera galwanometrycznego. W procesie cięcia zastosowano metodę wielokrotnych przejść, realizowanych w powietrzu bez gazu osłonowego, z prędkością skanowania $3.6$~m/s. Oznacza to, że pojedyncze przejście wiązki nad obszarem roboczym o długości kilkudziesięciu milimetrów trwało rząd dziesiątych części sekundy (np. dla ścieżki $L=36$~mm czas wynosi $t \approx 0.01$~s). Kluczowym parametrem procesu była zatem nie tyle długość pojedynczej ekspozycji, ile liczba powtórzeń, determinująca skumulowaną dawkę energii dostarczoną do materiału.

Analizie poddano dwa typy próbek: płyty CFRTP wytwarzane metodą formowania wtryskowego, zawierające włókna węglowe PAN (30\% wag.), oraz płyty CFRP na bazie żywicy epoksydowej i włókien PAN, o grubości 3~mm. Układ warstw w laminacie CFRP miał charakter przekładany (cross-ply 0/90$^{\circ}$, 12 warstw, zawartość włókien 70\%).

Efektywność procesu cięcia wiązką laserową była ściśle zależna od liczby przejść oraz trybu pracy źródła. Dla próbek CFRTP (ABS i PPS) uzyskano liniową zależność pomiędzy głębokością nacięcia a liczbą przejść wiązki, co pozwoliło na precyzyjne kontrolowanie procesu ablacji. Całkowite przecięcie płyty ABS następowało po około 15 przejściach, natomiast dla materiału PPS konieczne było 27 przejść przy mocy 2~kW. W obu przypadkach szerokość szczeliny na powierzchni próbki wynosiła ok. 500~$\mu$m, podczas gdy wewnątrz materiału zawężał się do 100--200~$\mu$m. Obserwacje z wykorzystaniem mikrotomografii rentgenowskiej wykazały ograniczone uszkodzenia cieplne, ograniczone do strefy przyściennej o grubości 100--130~$\mu$m.

W przypadku CFRP na bazie żywicy epoksydowej zależność efektywności od liczby przejść była bardziej złożona. Początkowo (do ok. 15 przejść) obserwowano wysoką i stabilną prędkość usuwania materiału, jednak w dalszych etapach proces ulegał spowolnieniu i wykazywał tendencję do nasycenia. Przy pracy w trybie ciągłym z mocą 3.3~kW konieczne było zastosowanie podwójnego śladu skanowania (z przerwą 0.1~mm) oraz do 50 przejść, aby uzyskać pełne przecięcie próbki. W trybie qcw (szczytowa moc impulsów 4.7~kW, wypełnienie 40\%, częstotliwość 800~Hz) całkowite cięcie osiągano po 25--30 przejściach. Szerokość szczeliny na powierzchni wynosiła wtedy ok. 450~$\mu$m, przy kerfie wewnętrznym rzędu 100~$\mu$m. Analiza przekrojów wskazała na obecność stref termicznego osłabienia żywicy (do 150~$\mu$m), a także zjawisk takich jak wysuwanie się włókien i lokalna recesja matrycy.

\subsection*{Specyfikacja źródła laserowego w badaniach własnych}

W odróżnieniu od opisanych w literaturze systemów dużej mocy bazujących na podczerwieni, w projektowanym systemie zastosowano niebieski moduł laserowy NICHIA NUBB23. Jest to zintegrowana macierz diod laserowych, charakteryzująca się emisją promieniowania o długości fali w zakresie $\lambda_d = 449{-}455$~nm (typowo 450~nm) \cite{bib:datasheetNUBB23}.

Zgodnie ze specyfikacją techniczną, moduł ten oferuje typową moc optyczną wyjściową $P_o = 22$~W przy pracy w trybie ciągłym i prądzie zasilania $I_F = 3.0$~A. Maksymalny dopuszczalny prąd pracy wynosi 3.5~A, a napięcie przewodzenia kształtuje się na poziomie $33.5$~V. Układ przystosowany jest do pracy w temperaturze obudowy ($T_c$) od $0^{\circ}$C do $70^{\circ}$C.

Wykorzystanie lasera o długości fali $\sim$450~nm jest uzasadnione wyższym współczynnikiem absorpcji światła niebieskiego przez materiały węglowe (CFRP) w porównaniu do standardowych laserów włóknowych (1064--1084~nm). Pozwala to na efektywne sprzęganie energii z materiałem mimo znacznie niższej mocy nominalnej (22~W) w porównaniu do rozwiązań przemysłowych (2~kW).

\subsection{Dobór geometrii uzębienia i struktury kinematycznej napędu}

W projektowaniu precyzyjnych mechanizmów celujących, istotnym zagadnieniem jest eliminacja luzów zwrotnych oraz drgań własnych przekładni, które bezpośrednio wpływają na błąd pozycjonowania lasera. Na podstawie analizy literatury przedmiotu, w projekcie zdecydowano się na zastosowanie kół zębatych o profilu strzałkowym.

W przeciwieństwie do klasycznego uzębienia prostego, koła strzałkowe zapewniają ciągłość zazębienia, co przekłada się na płynniejszą pracę przy wysokich prędkościach obrotowych. Jak wskazują Mo i in. w badaniach nad dynamiką układów napędowych, przekładnie te charakteryzują się „wyjątkową nośnością, wysokim współczynnikiem pokrycia oraz stabilnością transmisji” \cite{bib:Mo2025}. Co szczególnie istotne w kontekście projektowania elementów drukowanych w technologii 3D, specyficzna geometria powoduje wzajemne znoszenie się sił osiowych generowanych przez skośne zęby. Cecha ta pozwala na uproszczenie konstrukcji węzłów łożyskowych, eliminując konieczność stosowania ciężkich łożysk oporowych, które byłyby niezbędne w przypadku standardowych kół śrubowych \cite{bib:Mo2025}.

Wybór ten stanowi również fundament pod implementację docelowego układu kinematycznego w postaci przekładni planetarnej. Integracja uzębienia strzałkowego w systemie planetarnym pozwala na stworzenie napędu o wysokiej gęstości mocy, który jest samocentrujący i pozbawiony sił poosiowych działających na jarzmo czy koło słoneczne. Takie rozwiązanie łączy zalety kompaktowej budowy przekładni planetarnej z precyzją i cichobieżnością profilu strzałkowego.

Uzasadnienie doboru geometrii uzębienia znajduje również potwierdzenie w analizie dostępnych technologii wytwarzania. Dix i in. wskazują, że choć koła strzałkowe pozwalają na znaczną redukcję objętości przekładni przy zachowaniu zdolności do przenoszenia wysokich momentów obrotowych, ich konwencjonalna produkcja wiąże się z istotnymi ograniczeniami \cite{bib:Dix2023}. Tradycyjne metody ubytkowe, takie jak dłutowanie czy, wymuszają zazwyczaj zaprojektowanie technologicznego rowka pomiędzy lewą a prawą helisą uzębienia, niezbędnego dla wybiegu narzędzia skrawającego. Obecność tego rowka zwiększa całkowitą szerokość koła – często o 20--40\% względem szerokości czynnej – oraz może negatywnie wpływać na sztywność układu.

W projektowanym systemie platformy obrotowej ograniczenie to wyeliminowano poprzez zastosowanie technologii przyrostowych. Metoda ta uwalnia projektanta od restrykcji wynikających z kinematyki narzędzia skrawającego, umożliwiając wytworzenie kół o zwartej budowie, bez rowka technologicznego, w których obie części uzębienia stykają się bezpośrednio. Takie podejście pozwala na pełną integrację zalet mechanicznych opisanych przez Dixa – tj. płynności pracy i redukcji drgań – z minimalizacją masy i gabarytów, co jest krytyczne dla dynamiki układu śledzącego ATP.

\section{Synteza analizy i koncepcja autorska}

Na podstawie przeprowadzonej analizy literatury oraz zidentyfikowanych ograniczeń technologicznych, sformułowano koncepcję dwuetapowego rozwoju systemu śledzenia ATP. Analiza prac Seidaliyeva \cite{bib:Seidaliyeva2020} oraz Kemeshi \cite{bib:Kemeshi2024} wskazuje, że skuteczny system neutralizacji musi dynamicznie przełączać się między trybem detekcji na statycznym tle a trybem aktywnego śledzenia w ruchu. Oprócz wydajnej analizy obrazu, krytycznym elementem decydującym o precyzji celowania jest odpowiedni algorytm sterowania napędami, zdolny do kompensacji bezwładności całej platformy. Poniżej przedstawiono założenia dla etapu eksperymentalnego, będącego głównym przedmiotem badań niniejszej pracy, oraz koncepcję docelową skupiającą się na zwalczaniu bezzałogowych statków powietrznych.

\subsection*{Etap 1: Demonstrator technologii i badanie algorytmów sterowania}

W pierwszej fazie badań, stacjonarny system głowicy nadążnej ma za zadanie wykryć, a następnie precyzyjnie śledzić obiekt poruszający się ruchem jednostajnym lub wahadłowym w kontrolowanych warunkach, utrzymując na nim wiązkę laserową o znikomej mocy 5~mW. W fazie oczekiwania konstrukcja pozostaje nieruchoma, co zapewnia spełnienie warunku statycznego tła. Pozwala to na zastosowanie wydajnego algorytmu detekcji ruchu opartego na mieszaninie rozkładów Gaussa \cite{bib:Seidaliyeva2020}. Eliminuje to konieczność ciągłego przetwarzania obrazu przez obciążające sieci neuronowe, co znacząco minimalizuje opóźnienia początkowe.

Moment wykrycia ruchu stanowi sygnał wyzwalający przejście do fazy aktywnej. W tym momencie system uruchamia napęd w celu utrzymania obiektu w centrum kadru i przełącza się na algorytm śledzenia obiektowego, wspierany predykcją filtra Kalmana, estymującego przyszłą pozycję celu \cite{bib:Li2025}. Zastosowanie kamery typu \textit{Global Shutter} pełniłoby w tym procesie rolę pomocniczego zabiegu sprzętowego – eliminuje zniekształcenia geometryczne obiektu podczas szybkiego ruchu głowicy \cite{bib:Kemeshi2024}, co zapewnia stabilność danych wejściowych dla układu sterowania.

Głównym problemem badawczym na tym etapie staje się mechaniczna odpowiedź systemu celowniczego na wyliczony z obrazu wektor uchybu. W ramach pracy sformułowano cel eksperymentalnego porównania dwóch odmiennych paradygmatów sterowania pozycją modułu:
\begin{enumerate}
    \item \textbf{Płynnego regulatora proporcjonalno-różniczkującego (PD)}, którego nastawy poddawane są początkowej optymalizacji w dedykowanym środowisku symulacyjnym Gazebo.
    \item \textbf{Skokowego regulatora trójstawnego (ang. \textit{Bang-Off-Bang})}, zdefiniowanego strefą nieczułości (\textit{deadband}) dla minimalnego akceptowalnego uchybu.
\end{enumerate}
Zbadanie i zestawienie ze sobą tych dwóch struktur ma na celu wykazanie uwarunkowań związanych ze stosowaniem sterowania nieciągłego w systemach nadążnych. Hipoteza badawcza zakłada, że w algorytmie \textit{Bang-Off-Bang} zbyt szeroka strefa nieczułości skutkuje wyraźnym uchybem ustalonym (brakiem pokrycia wiązki lasera z centrum obiektu), natomiast jej zawężenie prowadzi do agresywnych wibracji mechaniki, co w sposób ciągły degraduje proces śledzenia. Płynna regulacja sygnału sterującego ma docelowo ten problem wyeliminować.

\subsection*{Etap 2: Koncepcja docelowa systemu antydronowego}

Docelowa aplikacja systemu zakłada adaptację opracowanych rozwiązań do zwalczania bezzałogowych statków powietrznych. W tym scenariuszu obiekt wykonuje gwałtowne, nieprzewidywalne manewry, co wymaga adaptacji zaimplementowanych modeli predykcyjnych. Dodatkowo, docelowa konstrukcja mechaniczna w układzie "T" (kamera i laser rozdzielone osiowo) wprowadza zagadnienie błędu paralaksy, który musi być kompensowany programowo w zależności od dystansu do celu.

Istotnym wyzwaniem pozostaje strategia przeszukiwania przestrzeni powietrznej. Ciągły ruch skanujący głowicy wyklucza stosowanie prostych metod detekcji wizyjnej ze względu na wysoką dynamikę i zmienność tła. Jako rozwiązanie rozwojowe proponuje się implementację strategii "skok i patrz" lub integrację platformy z zewnętrznym systemem wczesnego wykrywania (np. radar, kierunkowy detektor akustyczny). W takiej konfiguracji sensor nadrzędny wstępnie obraca układ w odpowiedni sektor, a system wizyjny przejmuje cel dopiero po mechanicznym ustabilizowaniu napędów, wykorzystując sprawdzoną w Etapie 1 kaskadę: szybką detekcję na zamrożonym tle, a następnie przejście w tryb ciągłego śledzenia \cite{bib:Seidaliyeva2020, bib:Kemeshi2024}.

%%%%%%%%%%%%%%%% TIPY %%%%%%%%%%%%%%%%
% Odwołania do literatury: 
% % książek \cite{bib:ksiazka},
% % artykułów w czasopismach \cite{bib:artykul}, 
% % materiałów konferencyjnych \cite{bib:konferencja}
% % i stron www \cite{bib:internet}.

% % \cite{bib:niino2016laser}

% Równania powinny być numerowane
% \begin{align}
% y = \frac{\partial x}{\partial t}
% \end{align}

%
%\begin{itemize}
%\item analiza tematu
%\item wprowadzenie do dziedziny (\english{state of the art}) – sformułowanie problemu, 
%\item poszerzone studia literaturowe, przegląd literatury tematu (należy wskazać źródła wszystkich informacji zawartych w pracy)
%\item opis znanych rozwiązań, algorytmów, osadzenie pracy w kontekście
%\item Tytuł rozdziału jest często zbliżony do tematu pracy. 
%\item Rozdział jest wysycony cytowaniami do literatury \cite{bib:artykul,bib:ksiazka,bib:konferencja}. 
%Cytowanie książki \cite{bib:ksiazka}, artykułu w czasopiśmie \cite{bib:artykul}, artykułu konferencyjnego \cite{bib:konferencja} lub strony internetowej \cite{bib:internet}.
%\end{itemize}

%\begin{Definition}\label{def:1}
%Definicja to zdanie (lub układ zdań) odpowiadające na pytanie o strukturze „co to jest a?”. Definicja normalna jest zdaniem złożonym z 2 członów: definiowanego (łac. definiendum) i definiującego (łac. definiens), połączonych spójnikiem definicyjnym („jest to”, „to tyle, co” itp.). 
%\end{Definition}
%
%\begin{Theorem}[Pitagorasa]\label{t:pitagoras}
%W dowolnym trójkącie prostokątnym suma kwadratów długości przyprostokątnych jest równa kwadratowi długości przeciwprostokątnej tego trójkąta. 
%\end{Theorem}
%
%\begin{Example}[generalizacja]\label{ex:generalizacja}
%Przykładem generalizacji jest para: zwierzę i pies. Pies jest zwierzęciem. Pies jest uszczegółowieniem pojęcia zwierzę. Zwierzę jest uogólnieniem pojęcia pies.
%\end{Example}

% TODO

\chapter{Koncepcja i projekt demonstratora systemu nadążnego} 

\section{Projekt mechaniczny platformy nadążnej}

Celem projektowania mechanicznego było założenie polegające na integracji cech systemu nadążnego czyli zdolności do śledzenia obiektu z wytrzymałą konstrukcją.

Z uwagi na powszechnie przyjętą nomenklaturę w dziedzinie robotyki, w niniejszej pracy wprowadzono ujednolicone nazewnictwo osi kinematycznych głowicy. Oś napędowa odpowiadająca za ruch w płaszczyźnie horyzontalnej (z ang. \textit{panning}) określona została mianem osi \textbf{PAN}. Z kolei oś realizująca ruch w płaszczyźnie wertykalnej (z ang. \textit{tilting}) zdefiniowana została jako oś \textbf{TILT}. W celu zachowania zwięzłości tekstu oraz spójności z anglojęzyczną literaturą branżową, autor w dalszej części pracy będzie posługiwał się wyłącznie tymi skrótowymi terminami.

\subsection{Założenia projektowe i koncepcja kinematyczna}

Proces syntezy układu mechanicznego demonstratora poprzedzono szczegółową analizą dostępnych rozwiązań komercyjnych oraz otwartych projektów inżynierskich, udokumentowanych w literaturze oraz materiałach audiowizualnych. Szczególną uwagę zwrócono na zrobotyzowane głowice kinematograficzne, stosowane na planach zdjęciowych do płynnego i wysoce precyzyjnego pozycjonowania sprzętu optycznego, a także na otwarte projekty zmotoryzowanych platform typu \textit{pan-tilt} wykonywanych m.in. w technologii druku 3D \cite{bib:isaac879_pantilt}. Główne wymagania stawiane projektowanej konstrukcji obejmowały minimalizację drgań przenoszonych na układ optyczny kamery, eliminację luzów mechanicznych oraz zdolność do szybkiej reorientacji układu w przestrzeni.

\newpage

Większość konwencjonalnych konstrukcji amatorskich zakłada umieszczenie całej logiki sterującej oraz zasilania w stałej, płaskiej podstawie urządzenia. W podstawowyh aplikacjach jest to uzasadnione, ponieważ ruchoma głowica przenosi na ogół jedynie prosty układ optyczny, niewymagający skomplikowanego okablowania. W przypadku projektowanego demonstratora uwarunkowania sprzętowe były jednak odmienne. Ze względu na minimalizm gabarytowy zastosowanej kamery, przy jednoczesnej dużej złożoności i liczbie wymaganych komponentów (takich jak platforma komputerowa Raspberry Pi, mikrokontroler ESP32, emiter lasera, moduły zasilania oraz sterowniki silników), klasyczne podejście skutkowałoby koniecznością poprowadzenia grubej i podatnej na uszkodzenia mechaniczne wiązki sygnałowej przez obrotowy przegub osi PAN.
Dlatego w niniejszej pracy zdecydowano się na zoptymalizowaną, odwróconą architekturę systemową. Cała elektronika obliczeniowa i wykonawcza została zintegrowana bezpośrednio wewnątrz ruchomej, hemisferycznej głowicy (Rys. \ref{fig:rozmieszczenie_komponentow}). Taki zabieg zredukował do absolutnego minimum liczbę przewodów podatnych na zginanie i skręcanie. Do wnętrza kopuły wprowadzono jedynie niezbędne okablowanie od zewnętrznie zamontowanych silników krokowych. Taka topologia, w odróżnieniu od napędów współosiowych, pozwala na ułatwione odprowadzanie ciepła z korpusów silników, zapewnia łatwy dostęp serwisowy.

\begin{figure}[H]
    \centering
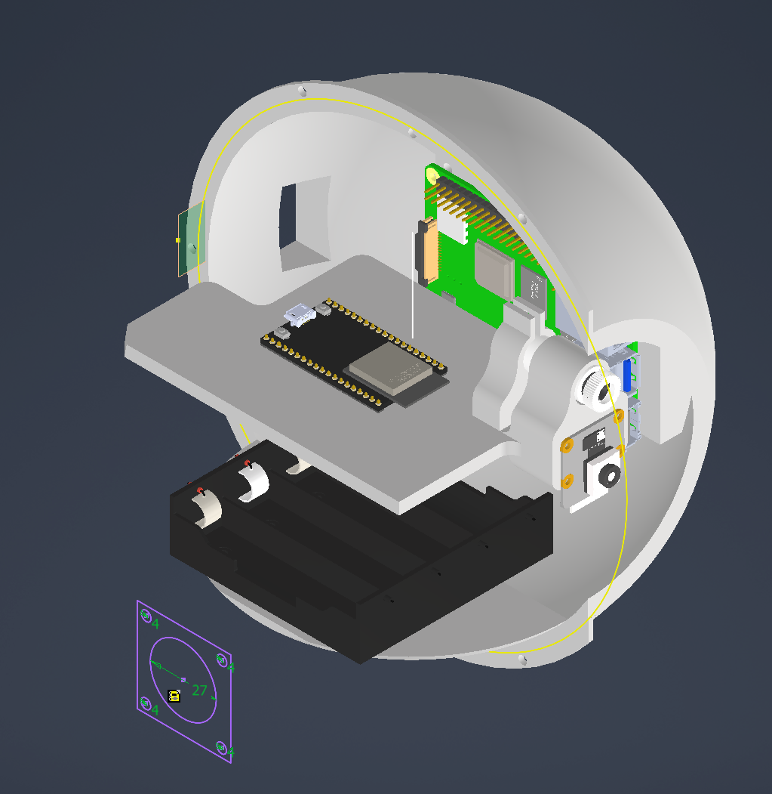
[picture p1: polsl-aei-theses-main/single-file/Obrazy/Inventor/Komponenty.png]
    
    \caption{Przekrój głowicy optyczno-elektronicznej zaprojektowanej w środowisku Inventor 2026, prezentujący architekturę systemową oraz rozmieszczenie komponentów obliczeniowych i zasilania.}
    \label{fig:rozmieszczenie_komponentow}
\end{figure}

Aby zapewnić stabilność tak obciążonej konstrukcji głowicy i zapobiec jej chwianiu podczas nagłych nawrotów, odstąpiono od stosowania cienkich osi obrotu. Zamiast tego zaimplementowano wielkogabarytowe łożysko wieńcowe o średnicy zewnętrznej $140\text{ mm}$ i wewnętrznej $80\text{ mm}$ (widoczne na Rys. \ref{fig:przekladnia_pan}). Jego zastosowanie pozwoliło na maksymalne poszerzenie bazy podparcia dla elementów obrotowych, co skutecznie przenosi momenty wywracające i niweluje luzy promieniowe układu.

Z punktu widzenia kinematyki i procesu montażowego, cały demonstrator został podzielony na trzy współpracujące ze sobą główne moduły mechaniczne:
\begin{itemize}
    \item \textbf{Moduł I: Stacjonarna podstawa} -- element gwarantujący stabilne osadzenie na podłożu. Ma postać płyty nośnej, w której zintegrowano centralny otwór montażowy pozycjonujący zewnętrzną bieżnię głównego łożyska (Rys. \ref{fig:przekladnia_pan}). Podstawa została wyposażona w nieruchomy wieniec zębaty o zębach daszkowych, z którym współpracuje zębnik układu napędowego osi PAN.
    \item \textbf{Moduł II: Ruchoma platforma nośna} -- element precyzyjnie spasowany z wewnętrzną średnicą łożyska, co zapewnia płynny obrót względem stacjonarnej podstawy (Rys. \ref{fig:jarzmo}). Z jego rdzenia wyprowadzono ramiona pionowe, na których zamontowano silniki krokowe. Silnik osi PAN współpracuje z wieńcem bazy, natomiast silnik osi TILT odpowiada za podnoszenie głowicy optycznej.
    \item \textbf{Moduł III: Głowica optyczno-elektroniczna} -- ruchoma czasza wyposażona we własną zębatkę napędową w płaszczyźnie TILT (Rys. \ref{fig:kopula_calosc}). Stanowi centrum sterowania układem. We wnętrzu zaprojektowano punkty montażowe pod obwody drukowane i moduły kamery oraz lasera, a w samej obudowie przewidziano otwory przepustowe na okablowanie silników. Moduł uzupełniono o zintegrowany przełącznik bistabilny do natychmiastowego odcinania zasilania aparatury w warunkach testowych.
\end{itemize}

\begin{figure}[h]
    \centering
    \begin{minipage}{0.48\textwidth}
        \centering
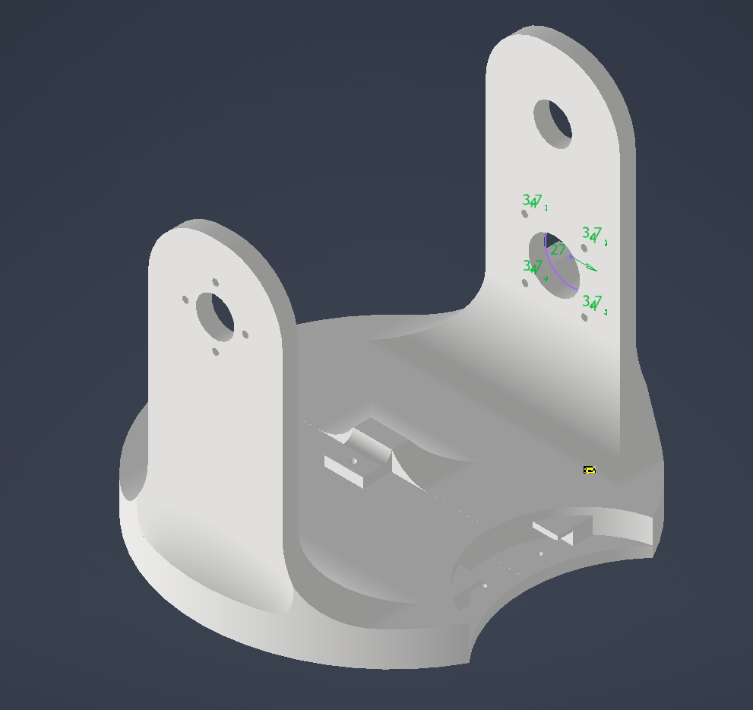
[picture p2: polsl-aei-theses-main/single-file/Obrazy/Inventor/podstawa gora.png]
        
        \caption{Model jarzma wsporczego (Moduł II) zapewniającego sztywność skrętną osi poziomej.}
        \label{fig:jarzmo}
    \end{minipage}\hfill
    \begin{minipage}{0.48\textwidth}
        \centering
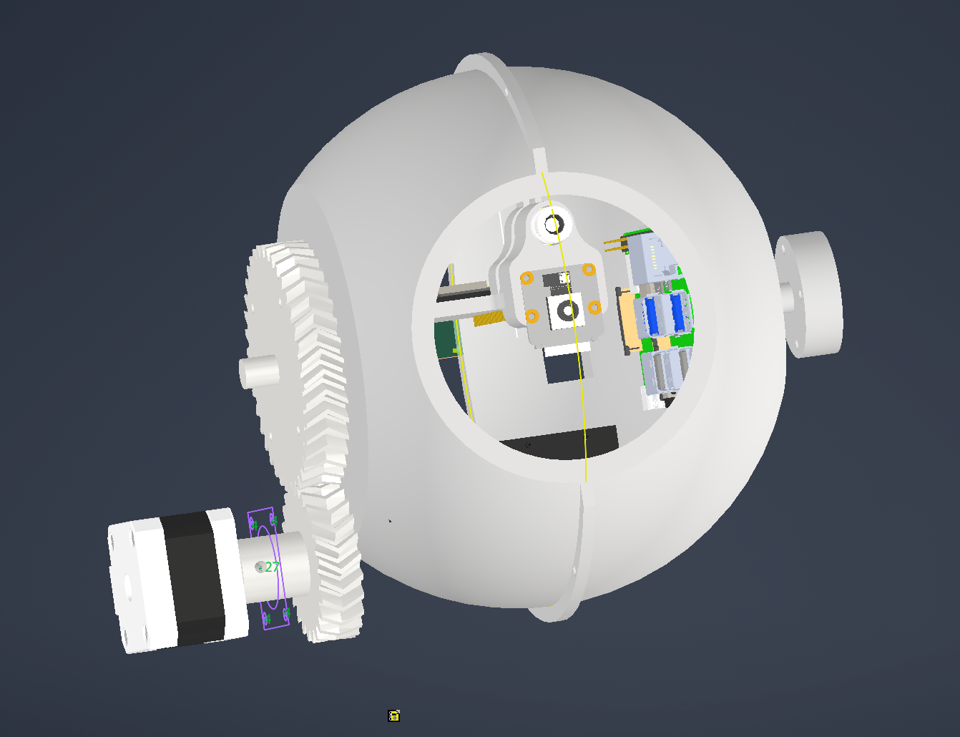
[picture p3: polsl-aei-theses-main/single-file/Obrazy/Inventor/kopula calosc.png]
        
        \caption{Zewnętrzny model ruchomej czaszy (Moduł III) ze zintegrowanym wieńcem napędowym osi TILT.}
        \label{fig:kopula_calosc}
    \end{minipage}
\end{figure}

\newpage
% \subsection{Modelowanie przestrzenne}

Wszystkie elementy mechaniczne demonstratora zostały zamodelowane z wykorzystaniem środowiska projektowego CAD 3D Autodesk Inventor 2026 (Rys. \ref{fig:zlozenie_boczne} oraz \ref{fig:zlozenie_tyl}). Cyfrowe odwzorowanie konstrukcji pozwoliło na weryfikację całkowitej przestrzeni roboczej demonstratora.

\begin{figure}[H]
    \centering
    \begin{minipage}{0.48\textwidth}
        \centering
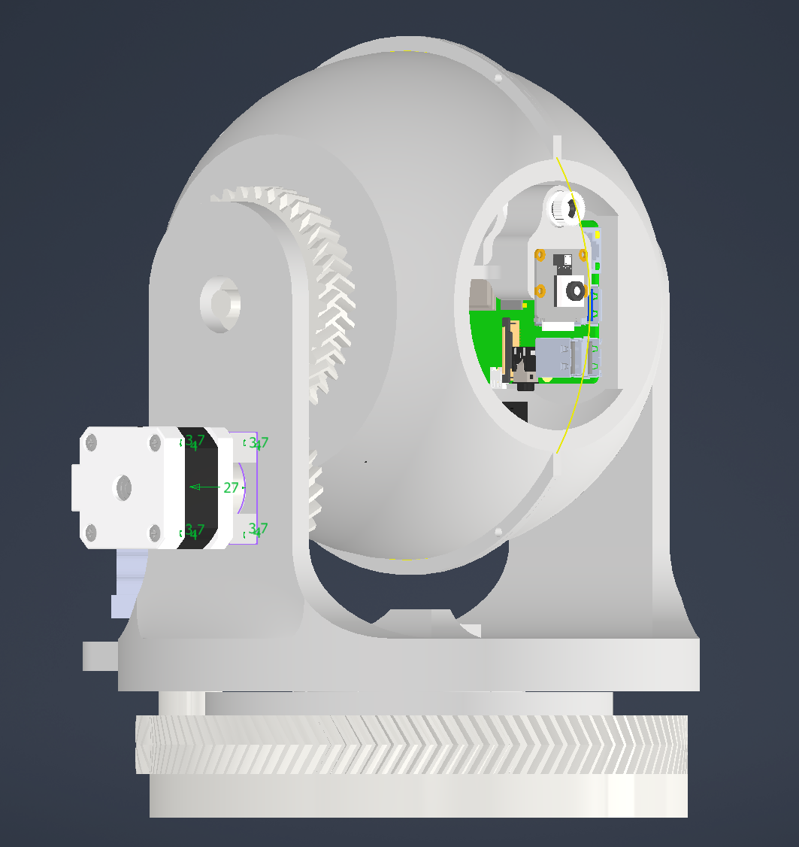
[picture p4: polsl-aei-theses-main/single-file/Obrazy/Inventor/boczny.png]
        
        \caption{Widok boczny kompletnego modelu przestrzennego demonstratora układu nadążnego.}
        \label{fig:zlozenie_boczne}
    \end{minipage}\hfill
    \begin{minipage}{0.48\textwidth}
        \centering
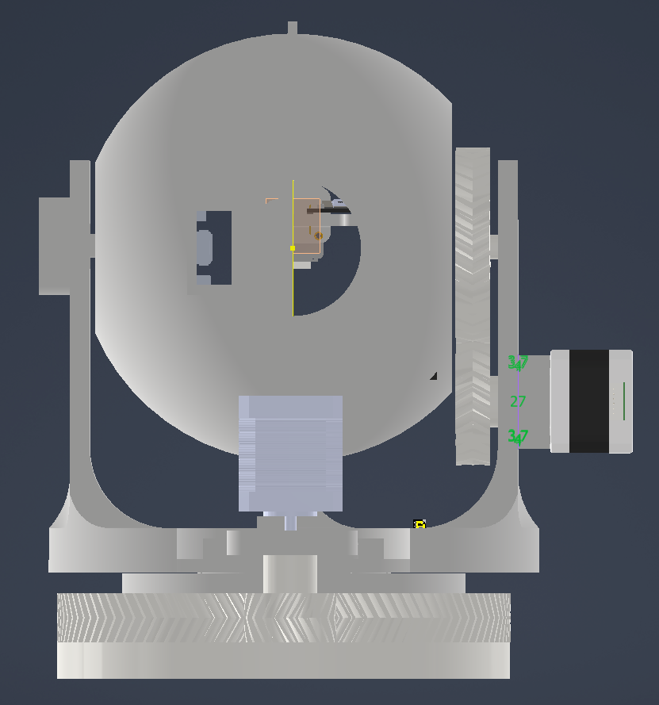
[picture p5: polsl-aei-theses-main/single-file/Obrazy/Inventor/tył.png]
        
        \caption{Widok tylny zespołu głowicy, obrazujący umiejscowienie napędów krokowych.}
        \label{fig:zlozenie_tyl}
    \end{minipage}
\end{figure}

\newpage

Szczególny nacisk podczas projektowania położono na optymalizację rozkładu mas. Zastosowanie dwuramiennego jarzma wsporczego (Moduł II) znacząco zwiększyło sztywność skrętną osi poziomej, zapobiegając ugięciom sprężystym, które dyskwalifikowałyby pomiary dokonywane przez algorytm wizyjny. Ponadto, półki i punkty mocowania wewnętrznej elektroniki oraz kamery z laserem w Module III (Rys. \ref{fig:kopula_przekroj}) dobrano tak, aby środek masy całej kopuły pokrywał się z fizyczną osią obrotu wału TILT. Zbalansowanie układu drastycznie zminimalizowało statyczny moment gnący, co pozwoliło ograniczyć prąd trzymania silników krokowych i zredukować generowanie ciepła.

\begin{figure}[h]
    \centering
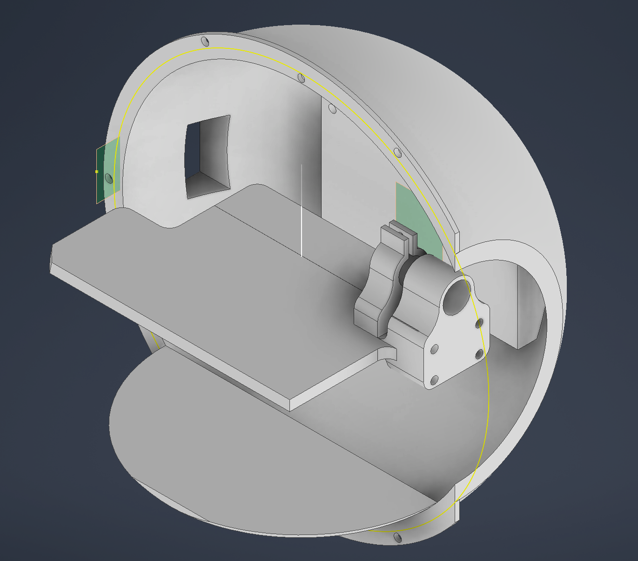
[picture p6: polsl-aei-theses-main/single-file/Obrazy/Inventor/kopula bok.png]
    
    \caption{Przekrój czaszy głowicy uwidaczniający wewnętrzne półki montażowe.}
    \label{fig:kopula_przekroj}
\end{figure}

\newpage
\subsection{Analiza układu napędowego i przekładni zębatej}

Zastosowanie tradycyjnych kół zębatych o zębach prostych zostało na wczesnym etapie odrzucone ze względu na pojawiające się zjawisko luzu międzyzębnego. Aby spełnić rygorystyczne wymagania układu celowania, w projekcie wdrożono przekładnie o zębach daszkowych (Rys. \ref{fig:przekladnia_pan}).

\begin{figure}[H]
    \centering
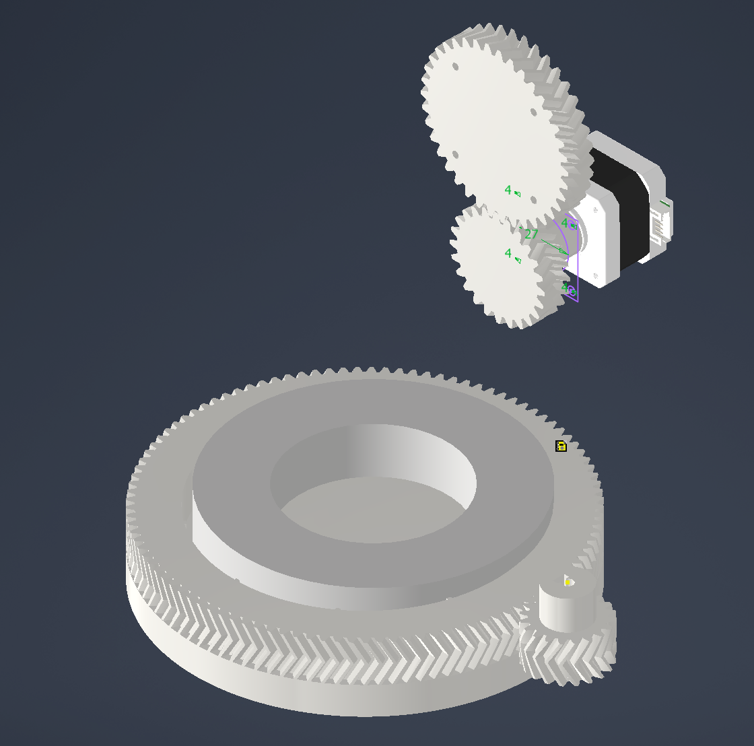
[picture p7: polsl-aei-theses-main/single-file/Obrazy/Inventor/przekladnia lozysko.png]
    
    \caption{Model przekładni o zębach daszkowych osi PAN oraz TILT.}
    \label{fig:przekladnia_pan}
\end{figure}

Pochylenie linii zęba w dwóch przeciwnych kierunkach powoduje wzajemne znoszenie się sił osiowych, co chroni łożyska silników krokowych przed przedwczesnym zużyciem. Co ważniejsze dla zastosowań robotycznych, zarys daszkowy charakteryzuje się samoosiowaniem współpracujących kół oraz dopuszcza ciaśniejsze spasowanie profilu. Pozwala to na mechaniczną eliminację luzu zwrotnego, zapobiegając szarpaniu i klatkowaniu obrazu przy szybkich zmianach kierunku śledzenia przez mikrokontroler sterujący.

Układ kinematyczny celowo zróżnicowano pod względem redukcji kątowej. Całkowite przełożenie mechaniczne $i$ określa się stosunkiem liczby zębów koła napędzanego $z_2$ do koła napędzającego $z_1$ \cite{bib:2012Pkm}:
\begin{equation}
    i = \frac{z_2}{z_1}
\end{equation}

Dla głównej osi obrotu (PAN), obciążonej znaczną bezwładnością obrotową Modułu II i III, zaprojektowano przekładnię o przełożeniu $i_{PAN} = 5.25$ ($z_1 = \text{20}$, $z_2 = \text{105}$). Z kolei dla osi podnoszenia (TILT), która operuje zbalansowaną masowo głowicą, zastosowano łagodniejsze przełożenie $i_{TILT} = 1.60$ ($z_3 = \text{24}$, $z_4 = \text{38}$).

\newpage
Zaimplementowane przełożenia bezpośrednio determinują fizyczną rozdzielczość kątową systemu $\Delta\theta$. Dla użytych napędów krokowych o podstawowym skoku wynoszącym $1.8^\circ$, rozdzielczość na wale wyjściowym wyraża się zależnością \cite{bib:WróbelTadeusz1993Ss}:
\begin{equation}
    \Delta\theta = \frac{1.8^\circ}{i \cdot \mu}
\end{equation}
gdzie $\mu$ oznacza zaimplementowany mnożnik podziału mikrokroku. Odpowiednie zwiększenie przełożenia redukcyjnego było niezbędne do utworzenia sprzętowego filtru dolnoprzepustowego, zdolnego do wygładzenia mikroskoków silnika i redukcji hałasu mechanicznego wywoływanego przez drobne oscylacje algorytmu śledzącego punkt docelowy. Gotowy, fizyczny model demonstratora zaprezentowano na Rysunku \ref{fig:gotowy_model}.

\begin{figure}[H]
    \centering
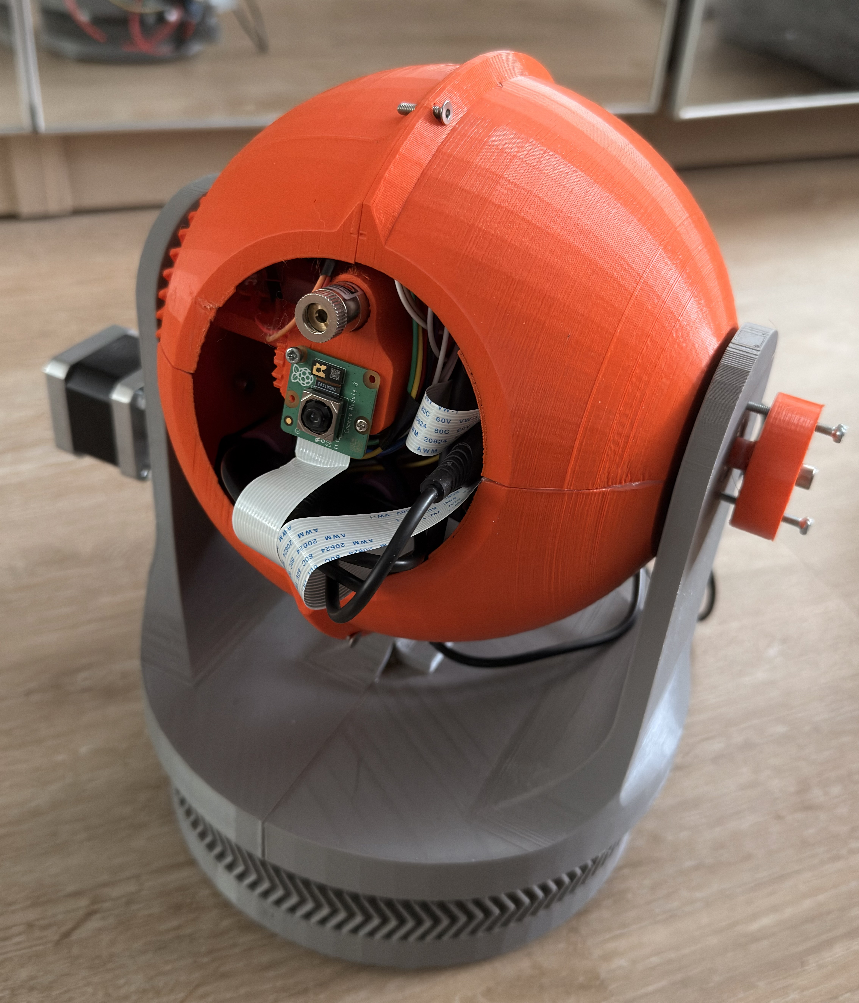
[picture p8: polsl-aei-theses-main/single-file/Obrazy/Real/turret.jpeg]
    
    \caption{Gotowy model demonstratora}
    \label{fig:gotowy_model}
\end{figure}

\section{Architektura sprzętowa i integracja elektroniczna}

Działanie zaprojektowanego układu mechanicznego wymagało implementacji odpowiednio dobranej warstwy elektronicznej. Ze względu na architekturę systemu, obejmującą ciągłą akwizycję strumienia wideo, przetwarzanie obrazu oraz precyzyjne sterowanie napędami, przyjęto rozproszoną architekturę sprzętową. W poniższej sekcji omówiono dobór komponentów, strukturę zasilania oraz fizyczne interfejsy wymiany danych.

\subsection{Dobór głównych komponentów systemu}

W architekturze systemu wyodrębniono dwa główne poziomy sterowania zlokalizowane bezpośrednio w głowicy: nadrzędny oraz wykonawczy. 

Jako jednostkę nadrzędną wykorzystano mikrokomputer \textbf{Raspberry Pi 4B} wyposażonemu w 8 GB pamięci RAM. Wybór tej platformy podyktowany był koniecznością budżetowego rozwiązania systemu wizyjnego oraz bezpośredniego wykonywania skryptów sterujących i komunikacyjnych. Duża pojemność pamięci operacyjnej jest istotna dla bezstratnej obsługi strumieni wideo oraz płynnego działania algorytmów detekcji wizyjnej zaimplementowanych z wykorzystaniem biblioteki OpenCV. 

Do akwizycji obrazu wykorzystano dedykowany moduł wizyjny \textbf{Raspberry Pi Camera Module 3}, który został podłączony do mikrokomputera z wykorzystaniem sprzętowego interfejsu szeregowego MIPI CSI (ang. \textit{Camera Serial Interface}) za pomocą elastycznej taśmy sygnałowej FFC. Zastosowanie tego interfejsu, w przeciwieństwie do kamer podłączanych przez port USB, znacząco zmniejsza obciążenie procesora oraz redukuje opóźnienia w przesyłaniu klatek obrazu do pamięci operacyjnej.

System operacyjny Raspberry Pi OS, jako system z podziałem czasu, nie gwarantuje determinizmu czasowego, co dyskwalifikuje go z bezpośredniego generowania precyzyjnych sygnałów dla sterowników silników. Z tego powodu w warstwie wykonawczej zaimplementowano platformę deweloperską \textbf{ESP32 DevKitC-32E V4} (bazującą na module ESP-WROOM-32E z łącznością Wi-Fi oraz Bluetooth 4.2). Zadaniem mikrokontrolera jest odbiór wyliczonych wartości uchybu oraz sprzętowe, rygorystyczne czasowo taktowanie impulsów sterujących mechaniką.

Do napędu osi PAN i TILT wykorzystano silniki krokowe w standardzie \textbf{NEMA 17}. Charakteryzują się one krokiem podstawowym wynoszącym $1.8^\circ$, co w połączeniu ze sprzętową redukcją przez przekładnie strzałkowe zapewnia wysoką rozdzielczość pozycjonowania. Wysterowanie silników realizowane jest przez zaawansowane sterowniki \textbf{Pololu 36v4 (High-Power Stepper Motor Driver 3730)}. Moduły te tolerują napięcie zasilania do 50 V i prąd ciągły na poziomie 4 A.

\newpage
System celowniczy oparto na wymiennych, niskomocowych modułach diod laserowych o mocy $5\text{ mW}$, zasilanych napięciem $5\text{ V}$ i emitujących wiązkę o długości fali $650\text{ nm}$. Zaprojektowany mechanizm mocowania umożliwia szybką wymianę głowic wyposażonych w różne soczewki kolimacyjne (generujące plamkę punktową lub krzyż). Pozwala to na weryfikację precyzji działania algorytmów śledzących punkt padania wiązki.

\subsection{Topologia zasilania i separacja obwodów}

W ramach realizacji projektu zaprojektowano rozbudowany układ zasilania, który uwzględnia specyficzne wymagania prądowe i napięciowe poszczególnych komponentów systemu.

Schemat sekcji zasilania (Rys. \ref{fig:schemat_zasilania}) opiera się na pakiecie czterech ogniw litowo-jonowych w układzie 4S (Li-Po 4S), dostarczającym nominlne napięcie na poziomie około 14.8~V (oznaczone jako główna szyna \texttt{+16V\_BATT} obrazujące maksymalne możliwe napięcie). Z głównego węzła zasilającego wyprowadzono trzy niezależne gałęzie zasilania:

\begin{enumerate}
    \item \textbf{Szyna wysokoprądowa napędów (\texttt{+16V\_BATT}):} Napięcie z pakietu ogniw poprowadzono bezpośrednio do złączy zasilających sterowniki silników. Ze względu na wysokie prądy rozruchowe silników krokowych, zdecydowano się na bezpośrednie zasilanie z baterii.
    \item \textbf{Gałąź logiczna jednostki nadrzędnej (\texttt{+5V\_RPi}):} Do zasilania mikrokomputera wykorzystano impulsową przetwornicę obniżającą Pololu D24V50F5, charakteryzującą się wysoką wydajnością prądową rzędu 5~A. Na wejściu przetwornicy zastosowano kondensator filtrujący o pojemności 470~$\mu$F, którego zadaniem jest tłumienie impulsów napięciowych powstających podczas włączania zasilania.
    \item \textbf{Gałąź peryferyjna efektora (\texttt{+5V\_LASER}):} Moduł lasera zasilany jest z przetwornicy obniżającej napięcie do 5~V. Takie odseparowanie gwarantuje, że wahania poboru prądu przez diodę laserową nie wpłyną na stabilność pracy jednostek obliczeniowych.
\end{enumerate}

\newpage
\begin{figure}[H]
    \centering
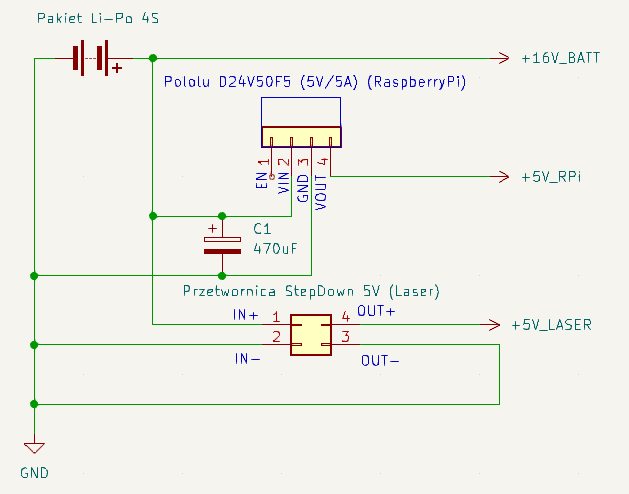
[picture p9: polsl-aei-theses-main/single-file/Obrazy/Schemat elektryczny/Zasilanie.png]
     
    \caption{Schemat ideowy układu zasilania uwzględniający pakiet ogniw 4S oraz przetwornice napięcia.}
    \label{fig:schemat_zasilania}
\end{figure}

\subsection{Jednostka nadrzędna, interfejsy i komunikacja}

Za zarządzanie systemem, przetwarzanie wizyjne i wyliczanie uchybu śledzenia odpowiada \textbf{mikrokomputer Raspberry Pi 4} (Rys. \ref{fig:schemat_mozgu}). Do sprzętowej akwizycji obrazu wykorzystano dedykowaną kamerę \textbf{Raspberry Pi Camera Module 3}. Rozwiązanie to pozwala na bezpośredni dostęp do strumienia wideo minimalizując opóźnienia transportowe w układzie zamkniętej pętli sprzężenia zwrotnego.

Mikrokontrolerem wykonawczym jest ESP32-DevKitC-32E V4. Połączenie pomiędzy jednostkami zrealizowano za pomocą przewodu USB, który pełni podwójną funkcję:
\begin{itemize}
    \item \textbf{Zasilającą:} Dostarcza napięcie 5~V bezpośrednio z portu Raspberry Pi do stabilizatora napięcia na płytce ESP32.
    \item \textbf{Komunikacyjną:} Umożliwia asynchroniczną transmisję szeregową danych o docelowych pozycjach kątowych obu osi, przy prędkości 115200~bps.
\end{itemize}

\newpage
\begin{figure}[H]
    \centering
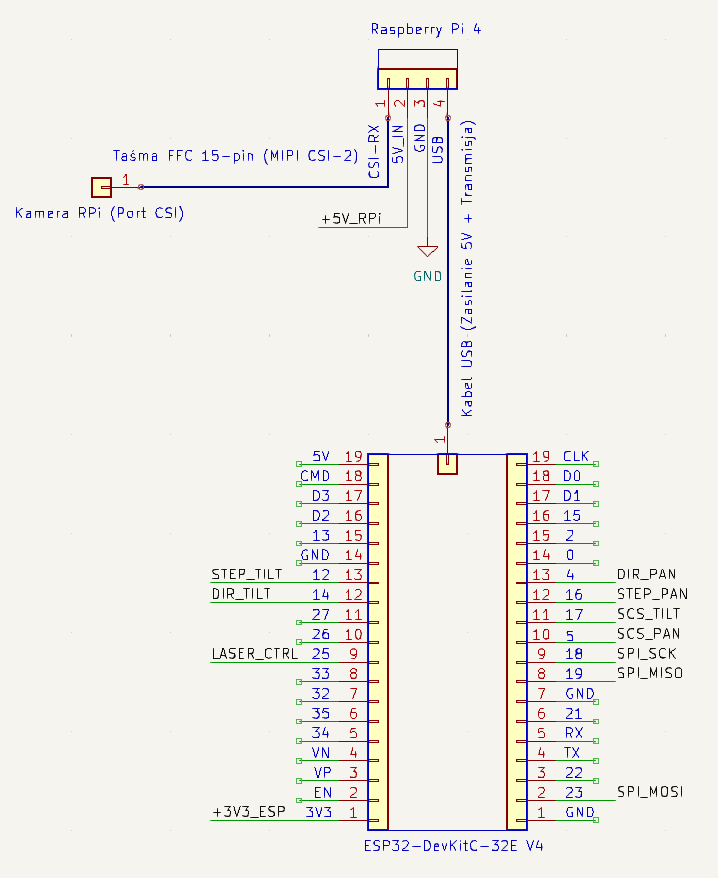
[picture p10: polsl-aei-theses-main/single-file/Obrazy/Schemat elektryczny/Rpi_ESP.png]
     % Podmień na właściwą nazwę pliku
    \caption{Architektura połączeń jednostki nadrzędnej (Raspberry Pi) z układem wykonawczym (ESP32).}
    \label{fig:schemat_mozgu}
\end{figure}

\newpage
\subsection{Układ wykonawczy napędów i magistrala SPI}

Za pozycjonowanie mechanizmu odpowiadają silniki krokowe NEMA 17, sterowane przez moduły Pololu 36v4 (Rys. \ref{fig:schemat_sterownikow}). Umożliwiają one precyzyjne mikrokrokowanie oraz programową kontrolę prądu cewek.

Integracja sterowników z płytą bazową i mikrokontrolerem ESP32 wymagała poprowadzenia następujących sygnałów sterujących:
\begin{itemize}
    \item \textbf{Zasilanie logiki:} Wykorzystano zintegrowany stabilizator LDO mikrokontrolera ESP32, doprowadzając napięcie referencyjne 3.3~V (\texttt{+3V3\_ESP}) do wejść \texttt{IOREF}, \texttt{SLEEP} oraz \texttt{RESET} obu sterowników.
    \item \textbf{Konfiguracja sprzętowa (SPI):} Magistrala SPI (\texttt{SPI\_MOSI}, \texttt{SPI\_MISO}, \texttt{SPI\_SCK}) jest współdzielona dla obu modułów. Indywidualne adresowanie podczas inicjalizacji odbywa się za pomocą linii wyboru układu: \texttt{SCS\_PAN} oraz \texttt{SCS\_TILT}.
    \item \textbf{Sygnały krok/kierunek:} Fizyczny ruch wymuszany jest poprzez sygnały logiczne na liniach \texttt{STEP\_PAN} / \texttt{DIR\_PAN} oraz \texttt{STEP\_TILT} / \texttt{DIR\_TILT}, obsługiwanych sprzętowo przez timery ESP32.
\end{itemize}

\begin{figure}[H]
    \centering
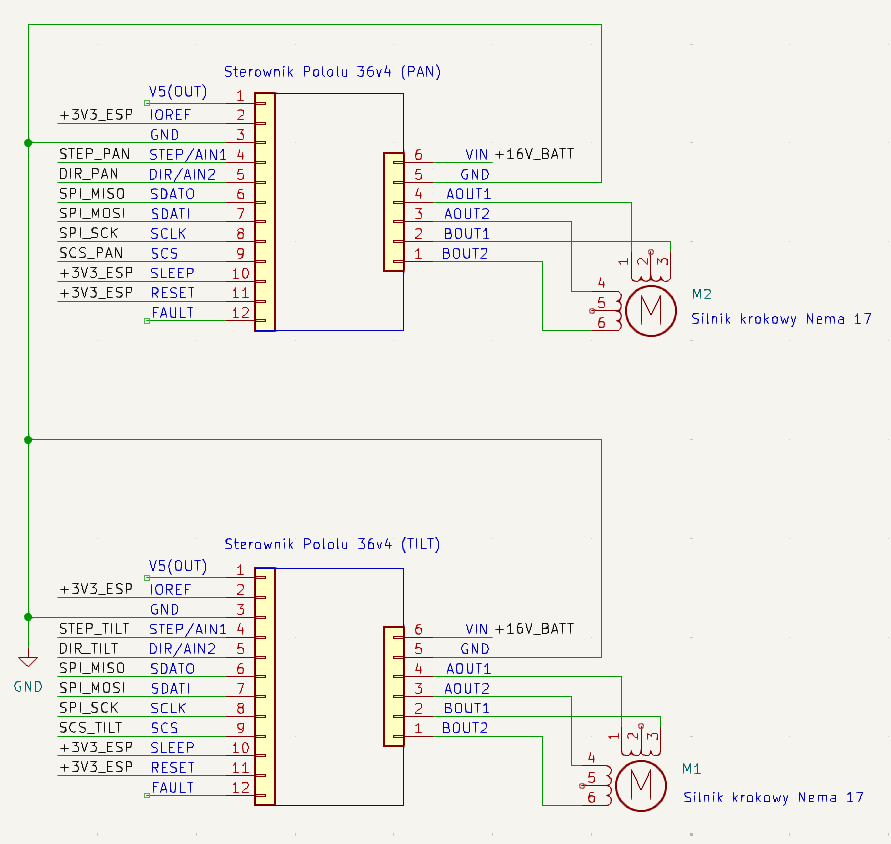
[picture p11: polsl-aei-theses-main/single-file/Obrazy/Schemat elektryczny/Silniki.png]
    
    \caption{Układ wykonawczy napędów PAN/TILT z wykorzystaniem sterowników Pololu 36v4 i komunikacji SPI.}
    \label{fig:schemat_sterownikow}
\end{figure}

\newpage
\subsection{Układ efektora}

System wyposażono w 5~mW moduł diody laserowej pełniący rolę wskaźnika punktu śledzenia. Piny wyjściowe GPIO mikrokontrolera ESP32 nie dysponują wydajnością prądową pozwalającą na bezpośrednie zasilenie emitera, dlatego zaimplementowano sprzętowy układ dopasowujący (Rys. \ref{fig:schemat_lasera}).

Do kluczowania obwodu wykorzystano tranzystor bipolarny NPN. Sygnał cyfrowy (\texttt{LASER\_CTRL}) z pinu 25 mikrokontrolera doprowadzono do bazy tranzystora poprzez rezystor ograniczający prąd o wartości 1~k$\Omega$. Zasilanie główne diody poprowadzono z niezależnej linii \texttt{+5V\_LASER}, a obwód zamyka się do masy poprzez złącze kolektor-emiter tranzystora.

\begin{figure}[H]
    \centering
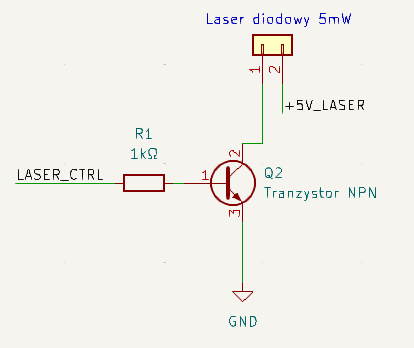
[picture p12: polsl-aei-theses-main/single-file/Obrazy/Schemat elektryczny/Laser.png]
    
    \caption{Schemat elektryczny układu kluczującego moduł lasera za pomocą tranzystora NPN.}
    \label{fig:schemat_lasera}
\end{figure}

%\begin{figure}
%\centering
%\includegraphics[width=0.5\textwidth]{./politechnika_sl_logo_bw_pion_pl.pdf}
%\caption{Podpis rysunku zawsze pod rysunkiem.}
%\label{fig:etykieta-rysunku}
%\end{figure}

% \begin{figure}[H]
%     \centering
%     % \includegraphics[width=0.9\textwidth]{sciezka_do_schematu_elektrycznego.png}
%     \caption{Schemat elektryczny układu sterowania, przedstawiający interfejsy komunikacyjne oraz kluczowanie diody laserowej.}
%     \label{fig:schemat_elektroniki}
% \end{figure}

\chapter{Architektura oprogramowania i symulacja systemu}

\section{Środowisko uruchomieniowe}
Złożoność współczesnych systemów robotycznych wymaga zastosowania wydajnego i niezawodnego środowiska programistycznego, które gwarantuje determinizm działania oraz powtarzalność wyników. Główną platformą deweloperską oraz stacją operatorską w opisywanym projekcie jest komputer przenośny wyposażony w procesor \textbf{[Intel Core i5-13500H]}, \textbf{16 GB} pamięci operacyjnej RAM oraz dedykowany układ graficzny \textbf{Intel Arc A350M}. Systemem operacyjnym hosta jest dystrybucja GNU/Linux Ubuntu w wersji 22.04 LTS (Jammy Jellyfish). Wybór ten podyktowany był natywnym wsparciem dla wybranych dystrybucji oprogramowania robotycznego oraz wysoką stabilnością jądra systemu. Edycję kodu źródłowego, zarządzanie repozytorium kontroli wersji (Git) oraz analizę logów realizowano w zintegrowanym środowisku programistycznym IDE Visual Studio Code.

W celu odizolowania zależności projektowych od głównego systemu operacyjnego oraz zapewnienia pełnej przenośności kodu, całe środowisko uruchomieniowe zostało zaimplementowane w architekturze kontenerowej z wykorzystaniem platformy Docker. Konteneryzacja eliminuje powszechny problem konfliktów wersji bibliotek programistycznych. Środowisko definiowane jest poprzez plik konfiguracyjny \texttt{Dockerfile}, który bazuje na oficjalnym, stabilnym obrazie \texttt{osrf/ros:humble-desktop}:

\newpage

\begin{lstlisting}[language=bash, basicstyle=\ttfamily\scriptsize, frame=single, breaklines=true]
FROM osrf/ros:humble-desktop

RUN apt-get update && apt-get install -y \
    ros-humble-cv-bridge \
    python3-opencv \
    ros-humble-foxglove-bridge \
    ros-humble-rviz2 \
    ros-humble-rviz-common \
    ros-humble-rviz-default-plugins \
    ros-humble-xacro \
    ros-humble-ros-gz \
    python3-pyqt5 \
    python3-numpy \
    ros-humble-image-transport \
    ros-humble-image-transport-plugins \
    ros-humble-rqt \
    ros-humble-rqt-common-plugins \
    ros-humble-rqt-image-view \
    python3-pip \
    python3-serial \
    nano \
    alsa-utils \
    mpg123 \
    gstreamer1.0-plugins-ugly \
    libsdl2-mixer-2.0-0 \
    && rm -rf /var/lib/apt/lists/*

RUN pip3 install pyzmq pygame pandas matplotlib "numpy<2"
\end{lstlisting}

Powyższa konfiguracja instaluje wszystkie pakiety niezbędne do pracy systemu. Obejmują one mosty komunikacyjne dla wizji maszynowej (\texttt{cv-bridge}, \texttt{python3-opencv}), środowiska symulacyjne i wizualizacyjne (\texttt{ros-gz}, \texttt{foxglove-bridge}, \texttt{rviz2}), narzędzia do transformacji modeli (\texttt{xacro}) oraz biblioteki interfejsów graficznych i przetwarzania danych dla języka Python (\texttt{pyqt5}, \texttt{numpy}, \texttt{pandas}, \texttt{matplotlib}). Dodatkowo zintegrowano pakiety obsługi multimediów (\texttt{alsa-utils}, \texttt{pygame}) do generowania dźwiękowych sygnałów w aplikacji GUI.

Uruchomienie tak spreparowanego środowiska następuje poprzez zbudowanie obrazu, a następnie wywołanie kontenera z odpowiednimi flagami przekierowującymi serwer wyświetlania X11:

\begin{lstlisting}[language=bash, basicstyle=\ttfamily\scriptsize, frame=single, breaklines=true]
docker build -t master_pan_tilt_env .

docker run -it --rm --net=host --device /dev/snd -e DISPLAY=$DISPLAY -v /tmp/.X11-unix:/tmp/.X11-unix -v ~/Robotyka/Master-Thesis/Color_detection_ros_Ubuntu:/workspace -w /workspace master_pan_tilt_env bash
\end{lstlisting}
\newpage
Po wykonaniu powyższej komendy użytkownik uzyskuje dostęp do powłoki \texttt{bash} wewnątrz hermetycznego środowiska z zainstalowanym i skonfigurowanym frameworkiem ROS 2 (Robot Operating System 2) w wersji Humble Hawksbill. Zastosowanie środowiska ROS 2 w stacji operatorskiej, pomimo implementacji głównych algorytmów na Raspberry Pi w trybie skryptowym, było konieczne z uwagi na potrzebę przeprowadzenia zaawansowanych symulacji fizycznych, łatwość modelowania kinematyki (TF2) oraz dostęp do potężnych narzędzi analitycznych, które w przyszłości pozwolą na łatwą rozbudowę układu o kolejne węzły decyzyjne.

\section{Implementacja w systemie ROS2}
\subsection{Architektura oprogramowania}
Struktura plików w przestrzeni roboczej ROS 2 została zorganizowana w sposób modułowy, zgodnie z wytycznymi narzędzia budującego \texttt{colcon}. Głównym pakietem integrującym zarówno aspekty wizualizacyjne, jak i symulacyjne jest \texttt{pan\_tilt\_description}. Drzewo katalogów prezentuje się następująco:

\begin{lstlisting}[basicstyle=\ttfamily\scriptsize, frame=single]
src/pan_tilt_description/
|-- CMakeLists.txt
|-- package.xml
|-- gui/
|   `-- turret_gui.py
|   `-- laser.mp3
|-- launch/
|   `-- sim_launch.py
|   `-- visualize_launch.py
|-- meshes/
|   `-- base_link.stl
|   `-- pan_link.stl
|   `-- tilt_link.stl
|-- rviz/
|   `-- config.rviz
|-- urdf/
|   `-- turret.urdf.xacro
`-- worlds/
    `-- tracking_world.sdf
\end{lstlisting}

Sercem warstwy interakcji z robotem fizycznym jest skrypt \texttt{turret\_gui.py} zlokalizowany w katalogu \texttt{gui/}. Aplikacja ta stanowi scentralizowane centrum kontroli, które używa niskolatencyjnej komunikacji asynchronicznej (ZeroMQ) z fizycznym mikrokontrolerem Raspberry Pi. Katalog \texttt{urdf/} oraz \texttt{meshes/} stanowią fundament dla modułu symulacyjnego, przechowując odpowiednio matematyczny opis łańcucha kinematycznego oraz rzeczywiste pliki przestrzenne STL wyeksportowane ze środowiska CAD, służące do symulacji działania algorytmów. Katalog \texttt{launch/} zawiera skrypty rozruchowe w języku Python, które automatyzują proces podnoszenia wielu węzłów symulacyjnych, wizualizacyjnych oraz mostów komunikacyjnych jednocześnie.

\section{Model symulacyjny w Gazebo}
Przed wdrożeniem i testowaniem algorytmów sterowania na rzeczywistym obiekcie fizycznym, przeprowadzono proces modelowania i weryfikacji w wirtualnym środowisku symulacyjnym, w celu zminimalizowanie ryzyka uszkodzenia sprzętu w wyniku niestabilności algorytmów regulacji.

\subsection{Definicja kinematyki - URDF i modele STL}
Model efektora został przeniesiony do przestrzeni wirtualnej przy użyciu formatu URDF (ang. \textit{Unified Robot Description Format}) sprzężonego z językiem makr XACRO. Struktura ta definiuje robota jako graf skierowany, w którym węzłami są fizyczne bryły, a krawędziami połączenia kinematyczne. W dołączonym pliku \texttt{turret.urdf.xacro} zdefiniowano trzy główne człony: nieruchomą podstawę (\texttt{base\_link}), obrotowe ramię poziome (\texttt{pan\_link}) oraz ruchomą głowicę wertykalną (\texttt{tilt\_link}). Pomiędzy nimi zdefiniowano połączenia typu \texttt{revolute}, narzucając im programowe limity wychyleń zgodne z rzeczywistą mechaniką.

W celu wiernego odwzorowania gabarytów i rozkładu mas, jako geometrie kolizyjne (\texttt{<collision>}) oraz wizualne (\texttt{<visual>}) wczytano przestrzenne pliki STL z katalogu \texttt{meshes/}. Modele te zostały uprzednio wyeksportowane ze środowiska Autodesk Inventor.

\subsection{Wirtualna sensoryka i silnik fizyki}
Do przeprowadzenia symulacji zachowania układu wykorzystano zaawansowane środowisko Gazebo. W obrębie definicji URDF umieszczono dedykowane wtyczki dla silnika symulacyjnego, które pełnią rolę cyfrowych bliźniaków fizycznych komponentów robota. Najistotniejszą z nich jest wirtualna kamera, zdefiniowana na końcu łańcucha kinematycznego (na członie \texttt{camera\_link}). Sensor ten generuje syntetyczny strumień wideo oraz dane macierzowe, zachowując przy tym parametry fizycznego układu optycznego. Kąt widzenia FOV ustalono na poziomie $1.396$ radiana, rozdzielczość na $640 \times 480$ pikseli (podyktowanej przez format kodowania przestrzeni barw RGB888), natomiast częstotliwość odświeżania na 30 Hz. Poniższy fragment kodu z pliku definiującego kinematykę układu wykonawczego prezentuje wdrożenie tego sensora oraz konfigurację tematu sieciowego dla systemu ROS 2:

\newpage
\begin{lstlisting}[language=XML, basicstyle=\ttfamily\small, frame=single, breaklines=true]
  <gazebo reference="camera_link">
    <sensor name="main_camera" type="camera">
      <camera>
        <horizontal_fov>1.396</horizontal_fov>
        <image>
          <width>640</width>
          <height>480</height>
          <format>R8G8B8</format>
        </image>
        <clip>
          <near>0.02</near>
          <far>100.0</far>
        </clip>
      </camera>
      <always_on>1</always_on>
      <update_rate>30</update_rate>
      <visualize>true</visualize>
      <topic>camera/image_raw</topic>
    </sensor>
  </gazebo>
\end{lstlisting}

Za wprawianie symulowanych członów konstrukcyjnych w ruch odpowiada wtyczka kontrolera trajektorii stawów (ang. Joint Position Controller). Narzędzie to zastępuje fizyczne silniki krokowe NEMA 17 i układy sterujące Pololu, realizując przemieszczenia bezpośrednio w silniku fizyki przy użyciu wewnętrznego regulatora PID. Otrzymuje ono żądany kąt za pomocą dedykowanego tematu ROS i aplikuje odpowiedni moment siły na wirtualny wał. Przykładowa implementacja tego węzła wykonawczego dla osi TILT została zdefiniowana następująco:

\newpage
\begin{lstlisting}[language=XML, basicstyle=\ttfamily\small, frame=single, breaklines=true]
  <gazebo>
    <plugin filename="libignition-gazebo-joint-position-controller-system.so"
            name="ignition::gazebo::systems::JointPositionController">
      <joint_name>tilt_joint</joint_name>
      <topic>model/pan_tilt_turret/joint/tilt_joint/cmd_pos</topic>
      <p_gain>5.0</p_gain>
      <i_gain>0.1</i_gain>
      <d_gain>0.5</d_gain>
    </plugin>
  </gazebo>
\end{lstlisting}

Integralną częścią całego środowiska symulacyjnego jest zamknięty wirtualny świat, w którym głowica nadążna przeprowadza proces śledzenia (Rys. \ref{fig:gazebo_sim}). Środowisko to zostało zdefiniowane w pliku \texttt{target\_world.sdf} i korzysta z silnika fizyki ODE (ang. Open Dynamics Engine). Oprócz podstawowych uwarunkowań takich jak grawitacja, oświetlenie kierunkowe czy płaszczyzna podłoża, wykreowano w nim dynamiczny obiekt referencyjny, nazywany kulą treningową. Obiekt ten powołano jako encję typu \texttt{actor}, co pozwala na jego przemieszczanie się w sposób deterministyczny, z pominięciem obciążeń wynikających z przeliczania rozbudowanej fizyki zderzeń. 
\newpage
\begin{figure}[H]
    \centering
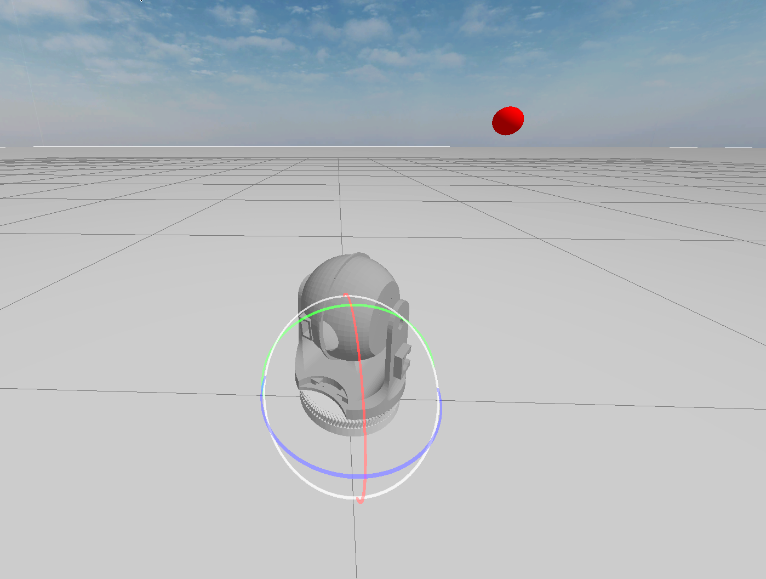
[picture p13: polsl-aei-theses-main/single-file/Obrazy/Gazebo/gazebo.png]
    
    \caption{Model symulacyjny układu wykonawczego umieszczony w środowisku Gazebo. W tle widoczny jest wirtualny obiekt referencyjny (sfera) poruszający się po zadanej trajektorii elipsy.}
    \label{fig:gazebo_sim}
\end{figure}

Kula o promieniu $0.15$ m i intensywnie czerwonym kolorze porusza się w pętli zamkniętej po zdefiniowanych punktach orientacyjnych, rysując w przestrzeni trajektorię o kształcie elipsy. Węzły trasy obejmują jednoczesne przemieszczenia w osiach Y oraz Z, zmuszając oba stawy platformy do ciągłej, zsynchronizowanej pracy. Odpowiedzialny za ten ruch fragment kodu przedstawiono poniżej:

\newpage
\begin{lstlisting}[language=XML, basicstyle=\ttfamily\small, frame=single, breaklines=true]
    <actor name="target_ball">
      <link name="link">
        <visual name="visual">
          <geometry><sphere><radius>0.15</radius></sphere></geometry>
          <material>
            <ambient>1 0 0 1</ambient>
            <diffuse>1 0 0 1</diffuse>
          </material>
        </visual>
      </link>
      <script>
        <loop>true</loop>
        <delay_start>0.0</delay_start>
        <auto_start>true</auto_start>
        <trajectory id="0" type="square">
           <waypoint><time>0.0</time><pose> 1.5 3.0 0.5 0 0 0</pose></waypoint>
           <waypoint><time>2.0</time><pose>-1.5 3.0 0.5 0 0 0</pose></waypoint>
           <waypoint><time>4.0</time><pose>-1.5 3.0 1.2 0 0 0</pose></waypoint>
           <waypoint><time>6.0</time><pose> 1.5 3.0 1.2 0 0 0</pose></waypoint>
           <waypoint><time>8.0</time><pose> 1.5 3.0 0.5 0 0 0</pose></waypoint>
        </trajectory>
      </script>
    </actor>
\end{lstlisting}

Tak przygotowane i w pełni zautomatyzowane środowisko pozwala algorytmom analitycznym powtarzalnie uczyć się reakcji na zadany bodziec ruchowy, co jest bezpośrednio wykorzystywane w procesie samostrojenia optymalnych nastaw regulatora PID.

\newpage
\subsection{Wizualizacja w środowisku Foxglove}
Jako platofrmę do wizualizacji danych telemetrycznych wykorzystano narzędzie \textbf{Foxglove Studio}.Dzięki instalacji pakietu \texttt{ros-humble-foxglove-bridge}, symulowany strumień wideo z Gazebo, a także bieżące parametry odchylenia kątowego poszczególnych stawów są strumieniowane na zewnątrz kontenera przez protokół WebSocket. Foxglove pozwala na konstruowanie wysoce responsywnych pulpitów analitycznych, w których zintegrowano widok przestrzenny 3D z nałożonymi wektorami sił oraz macierze obrazu RGB.

\subsection{Algorytm samouczenia i optymalizacji nastaw}
Jednym z kluczowych elementów badawczych było opracowanie w środowisku symulacyjnym algorytmu poszukującego optymalnych nastaw regulatora PID. Zamiast manualnie dobierać wzmocnienia na obiekcie fizycznym, w wirtualnym świecie umieszczono sferyczny obiekt o zadanym kolorze, podlegający ciągłemu ruchowi harmonicznemu.

Zaimplementowany węzeł cyklicznie uruchamia symulację śledzenia, perturbując parametry wektora nastaw $K = [K_p, K_i, K_d]$. Algorytm ten na podstawie syntetycznego obrazu oblicza w czasie rzeczywistym uchyb średniokwadratowy położenia pikseli obiektu od centrum kamery. Stan procesu optymalizacji uwidoczniony jest w podglądzie wizyjnym algorytmu (Rys. \ref{fig:auto_tuning}), gdzie nałożono dane telemetryczne (m.in. aktualne testowane wartości P, I, D oraz numer iteracji zwanej epoką). 

Po każdej iteracji wirtualnego ruchu, system automatycznie koryguje nastawy w kierunku gradientu spadku błędu, zachowując stabilność pętli sprzężenia zwrotnego. Po konwergencji algorytmu i ustaleniu optymalnych parametrów w sterylnym środowisku wirtualnym, wyliczone nastawy są walidowane i zapisywane jako wartości startowe.
\newpage
\begin{figure}[H]
    \centering
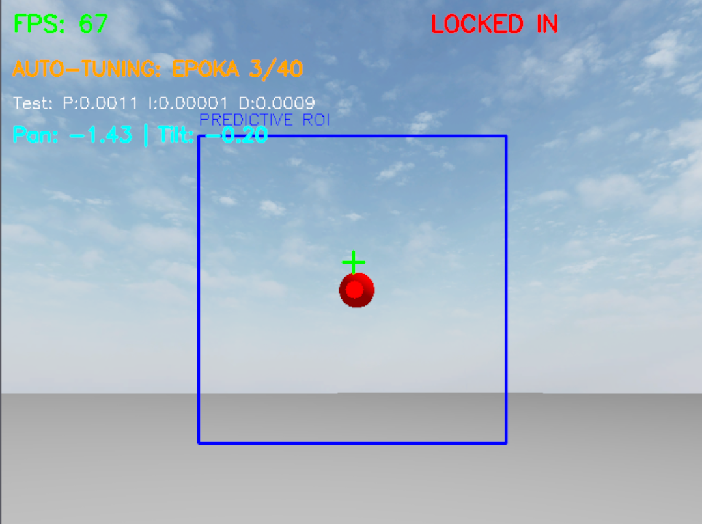
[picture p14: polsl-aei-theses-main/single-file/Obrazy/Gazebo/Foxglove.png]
    
    \caption{Interfejs nakładki diagnostycznej w trybie samouczenia w środowisku symulacyjnym Gazebo. Zrzut ekranu prezentuje 3 epokę uczenia, wyliczone na żywo kąty PAN/TILT oraz aktualne wartości nastaw regulatora PID weryfikowane na wykrytym i ograniczonym ramką obiekcie referencyjnym.}
    \label{fig:auto_tuning}
\end{figure}

\chapter{Algorytmy wizyjne i układy sterowania}

\section{Implementacja algorytmów detekcji i śledzenia}
System wizyjny demonstratora został zrealizowany w architekturze rozproszonej, w której wyodrębniono węzeł akwizycyjno-obliczeniowy oparty na mikrokomputerze Raspberry Pi oraz nadrzędną stację operatorską. W celu maksymalizacji wydajności obliczeniowej oraz minimalizacji opóźnień transmisji, skrypty wizyjne na jednostce pokładowej uruchamiane są natywnie w systemie operacyjnym Rasbian, z pominięciem warstw wirtualizacji. Detekcja celu opiera się na kaskadowej analizie obrazu z wykorzystaniem biblioteki OpenCV. W pierwszej fazie algorytm wykorzystuje metodę odejmowania tła do wykrywania ruchu, co pozwala na dynamiczne wyznaczenie zawężonego obszaru zainteresowania ROI. Dopiero w obrębie tego obszaru następuje progowanie w przestrzeni barw HSV. Takie podejście drastycznie redukuje obciążenie procesora, eliminując konieczność analizy całej klatki obrazu. 

Aby zapewnić ciągłość śledzenia w przypadku chwilowej utraty widoczności obiektu na skutek okluzji, w systemie zaimplementowano dyskretny filtr Kalmana pełniący funkcję estymatora stanu. Algorytm ten, na podstawie wektorów pozycji z poprzednich klatek, dokonuje predykcji przyszłego położenia celu, co zapobiega gwałtownym skokom uchybu regulacji. Całość procesu monitorowana jest przez dedykowany interfejs operatorski GUI zrealizowany przy użyciu biblioteki PyQt5. Aplikacja ta wizualizuje na żywo obraz z nałożonymi znacznikami obszaru śledzenia, maskę binarną przydatną do kalibracji warunków oświetleniowych, a także pozwala na asynchroniczną rejestrację danych pomiarowych do plików środowiska analitycznego bez obciążania pętli głównej mikrokontrolera.

\subsection{Węzeł akwizycyjno-obliczeniowy}
Zasadniczym elementem oprogramowania pokładowego jest skrypt analityczny realizujący proces przetwarzania obrazu i wypracowywania sygnałów sterujących. Proces ten rozpoczyna się od sprzętowej akwizycji danych wizyjnych. Zamiast obciążać główny skrypt w języku Python obsługą matrycy światłoczułej na niskim poziomie, wykorzystano wbudowane w system Linux narzędzia do obsługi potoku wideo. Strumień generowany jest jako niezależny proces w tle za pomocą wywołania powłoki systemowej, która kompresuje obraz do formatu MJPEG i udostępnia go na lokalnym porcie protokołu TCP:

\begin{lstlisting}[language=bash, basicstyle=\ttfamily\small, frame=single, breaklines=true]
while true; do rpicam-vid -n -t 0 --width 640 --height 480 --framerate 30 --codec mjpeg --listen -o tcp://0.0.0.0:5000; sleep 1; done
\end{lstlisting}
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

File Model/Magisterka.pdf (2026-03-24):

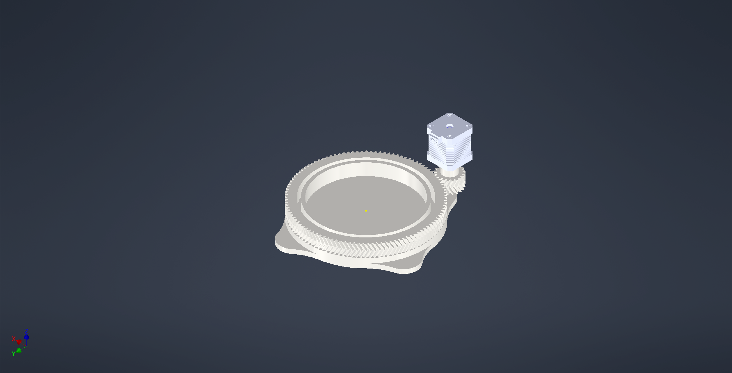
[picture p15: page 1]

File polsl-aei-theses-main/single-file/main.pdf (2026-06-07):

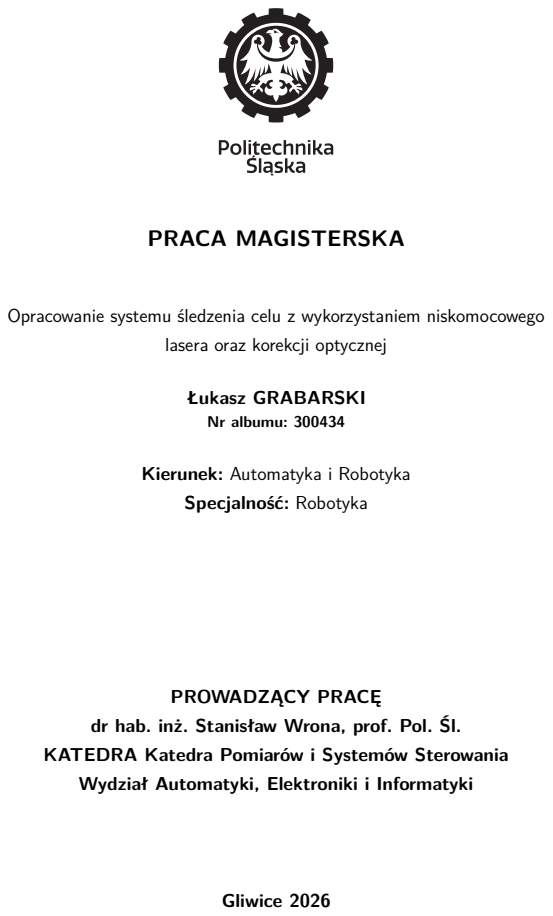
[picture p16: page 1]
PRACA MAGISTERSKA; Łukasz GRABARSKI; Nr albumu: 300434; PROWADZĄCY PRACĘ; Gliwice 2026

Opracowanie systemu śledzenia celu z wykorzystaniem niskomocowego

lasera oraz korekcji optycznej

Kierunek: Automatyka i Robotyka
Specjalność: Robotyka

dr hab. inż. Stanisław Wrona, prof. Pol. Śl.

KATEDRA Katedra Pomiarów i Systemów Sterowania
Wydział Automatyki, Elektroniki i Informatyki

Tytuł pracy

Opracowanie systemu śledzenia celu z wykorzystaniem niskomocowego lasera oraz korekcji optycznej

Streszczenie

Celem pracy jest zaprojektowanie i wykonanie demonstratora systemu kierowania niskomocowym laserem, zdolnego do automatycznego śledzenia poruszającego się celu na podstawie danych wizyjnych. W systemie zastosowany zostanie dedykowany marker w celu ułatwienia detekcji i korekcji trajektorii wiązki. System będzie symulował neutralizację celu poprzez utrzymanie wiązki lasera na markerze przez określony czas.

Słowa kluczowe

Laser niskomocowy, BSP, system śledzenia, korekcja optyczna, neutralizacja celu.

Thesis title

Development of a target tracking system using a low-power laser and optical correction
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

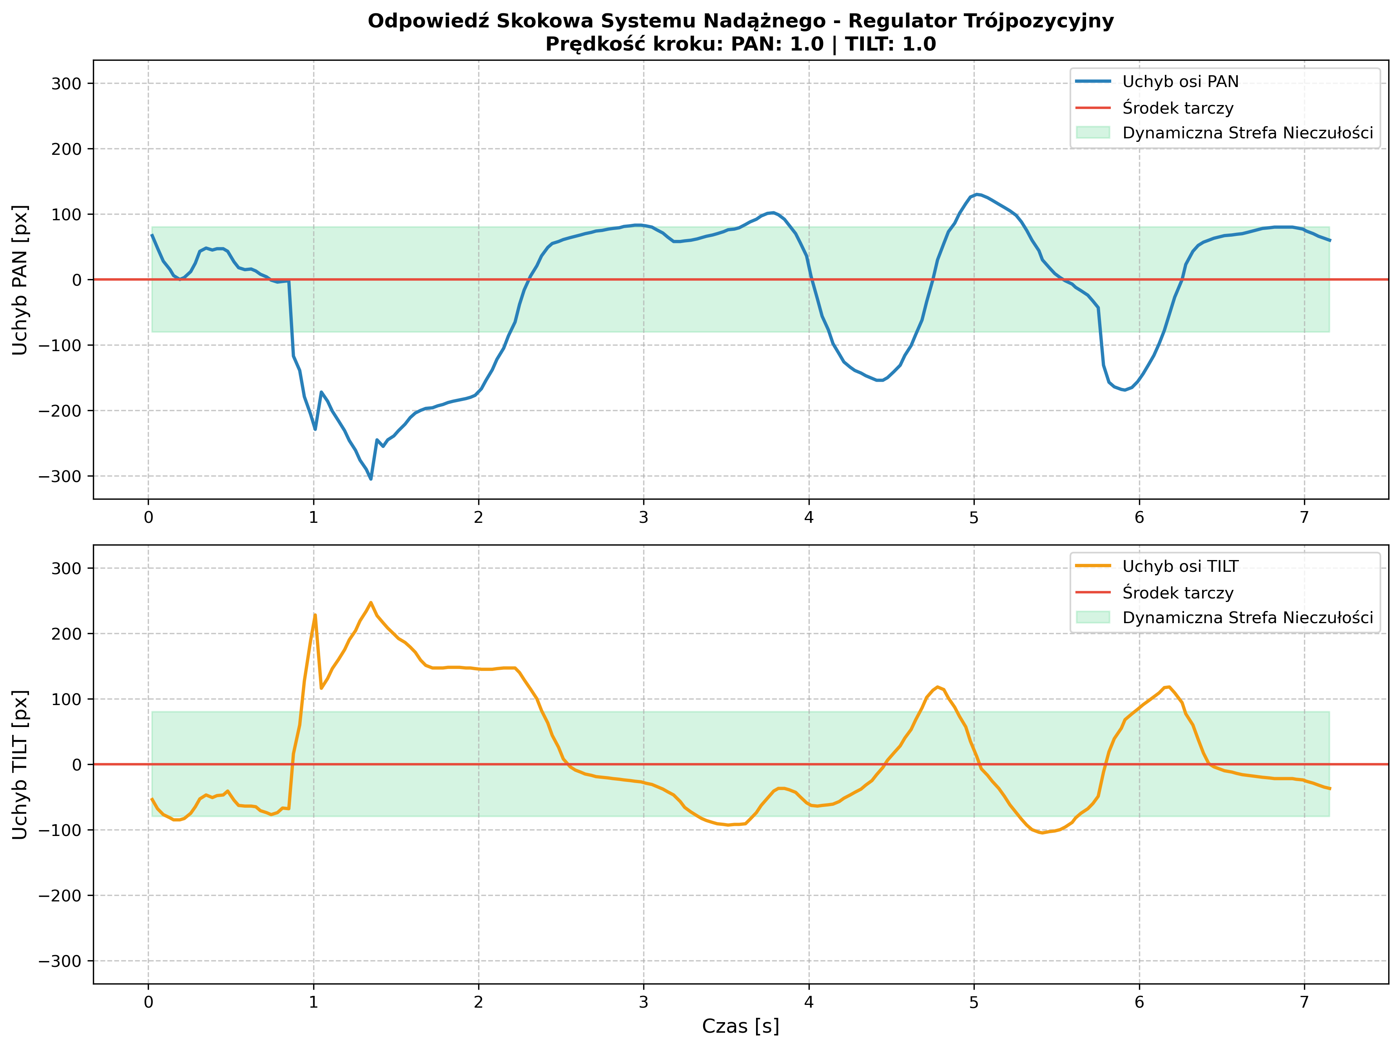
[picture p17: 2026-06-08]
polsl-aei-theses-main/single-file/Obrazy/WYniki troj/wykres_UP_BB_move_30_cm.png

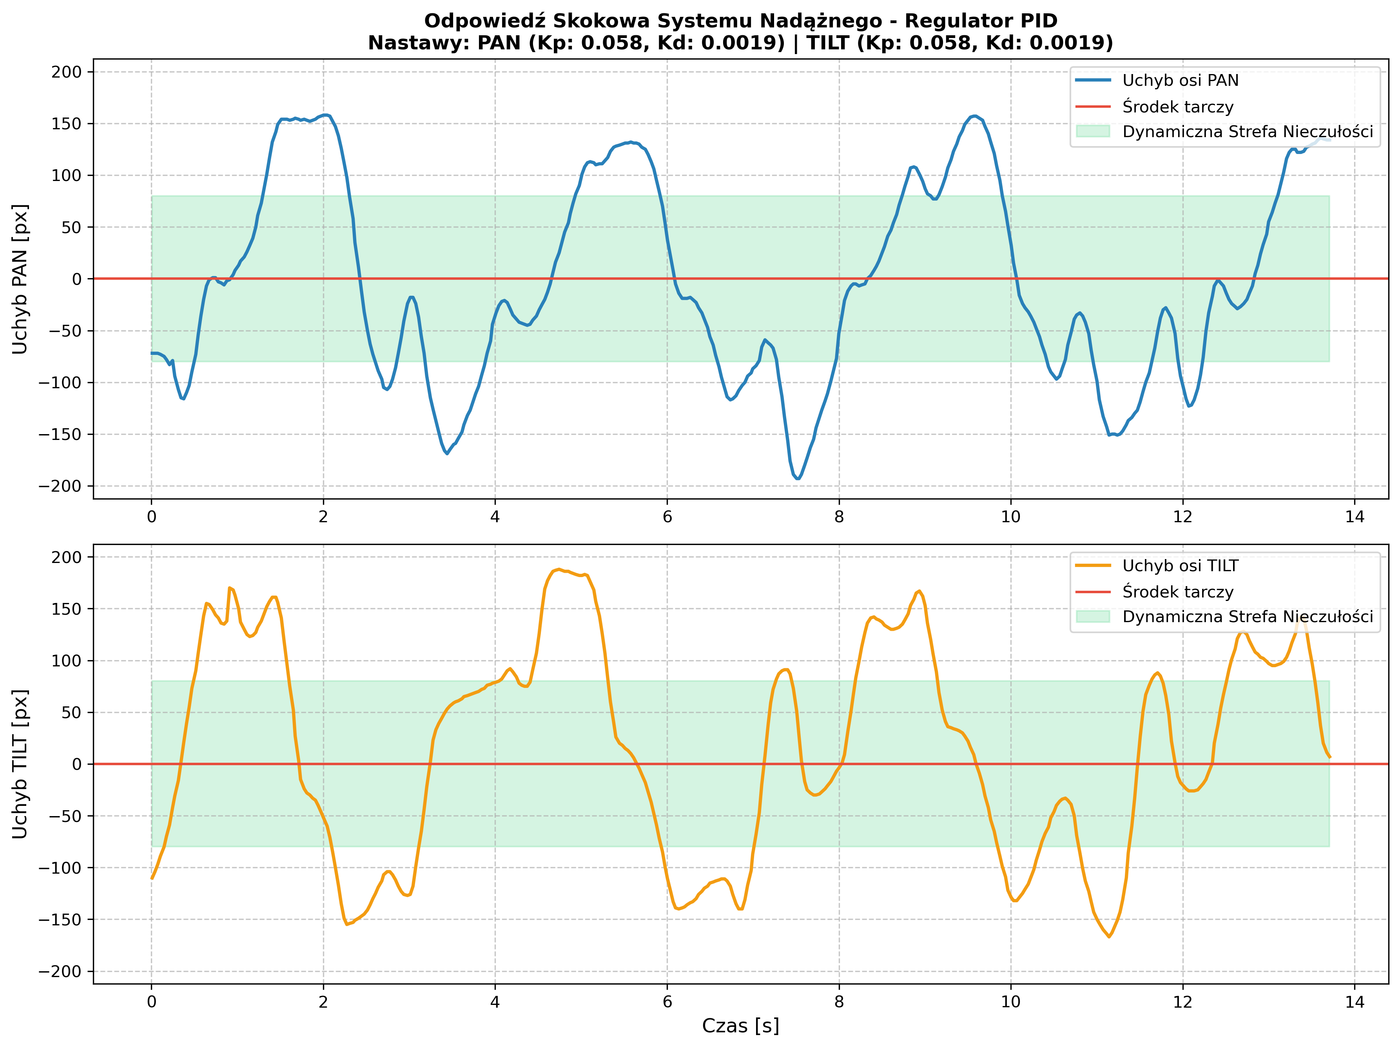
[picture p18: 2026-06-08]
polsl-aei-theses-main/single-file/Obrazy/Wyniki PID/wykres_UP_PID_circural_80_cm.png

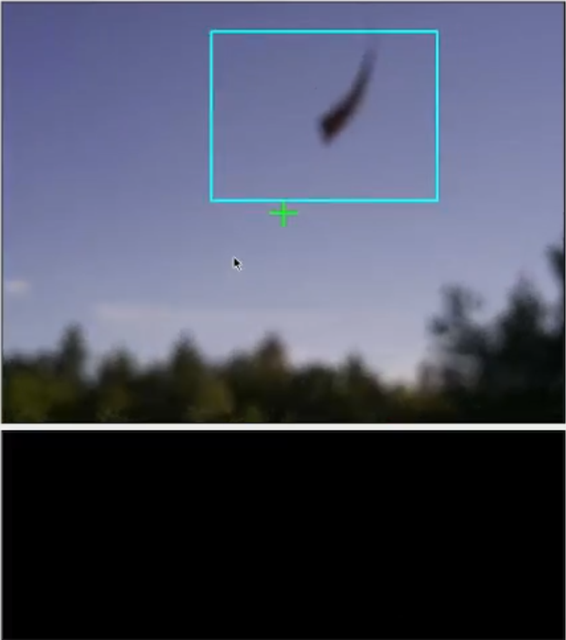
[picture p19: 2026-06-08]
polsl-aei-theses-main/single-file/Obrazy/Gazebo/Bad_2.png

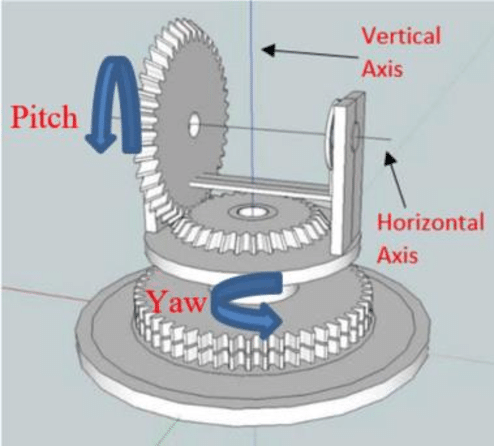
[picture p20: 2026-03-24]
polsl-aei-theses-main/single-file/Obrazy/Automated-Pan-Tilt-Head-3.png

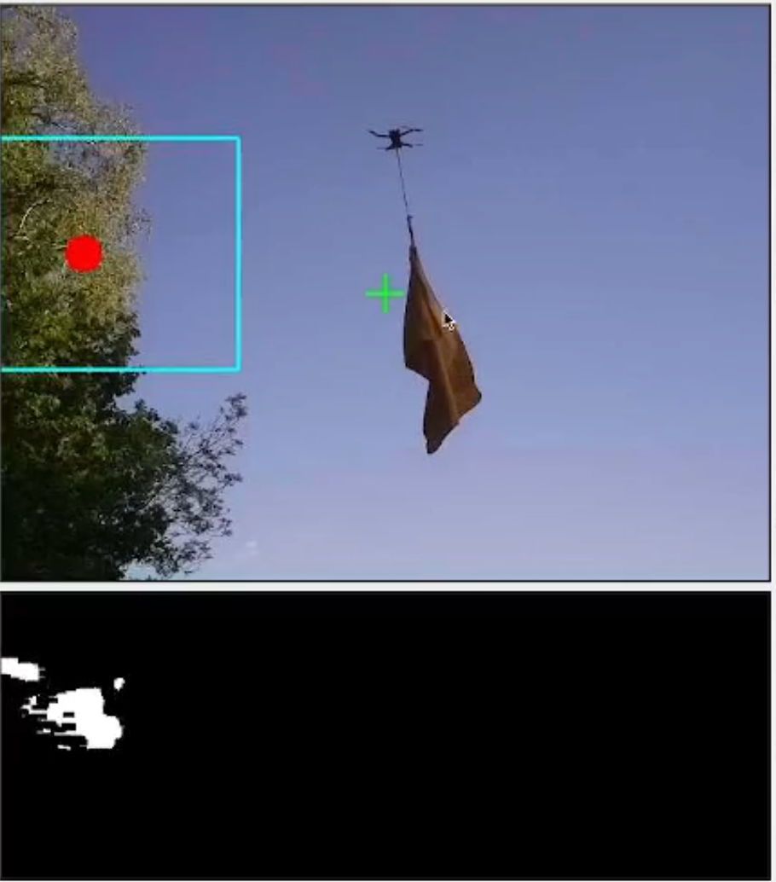
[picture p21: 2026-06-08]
polsl-aei-theses-main/single-file/Obrazy/Gazebo/Bad_3.png

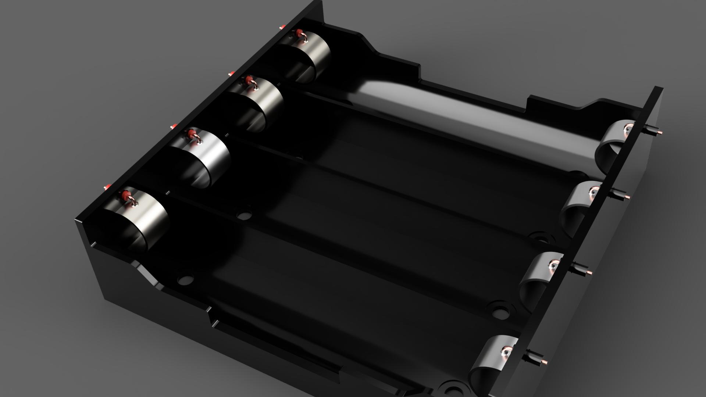
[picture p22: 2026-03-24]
Model/Magisterka/18650-cell-holder-1.snapshot.1/18650 Cell Holder 3.jpg

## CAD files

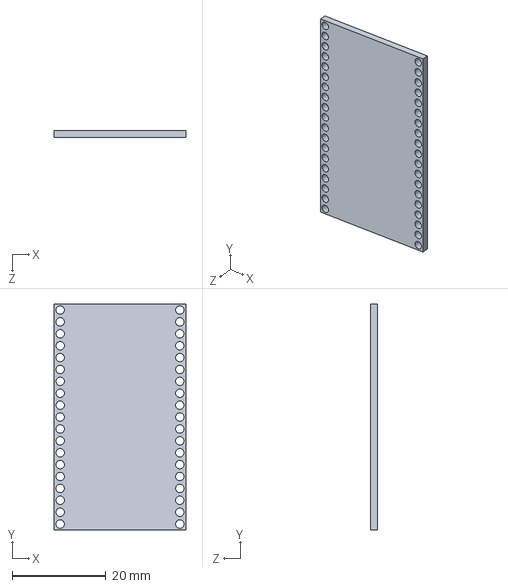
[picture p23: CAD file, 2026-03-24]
Model/Magisterka/esp32-devkitc-v4-1.snapshot.1/ESP-WROOM-32D-Export/Main-PCB.SLDPRT
28.1 x 48.3 x 1.60 mm

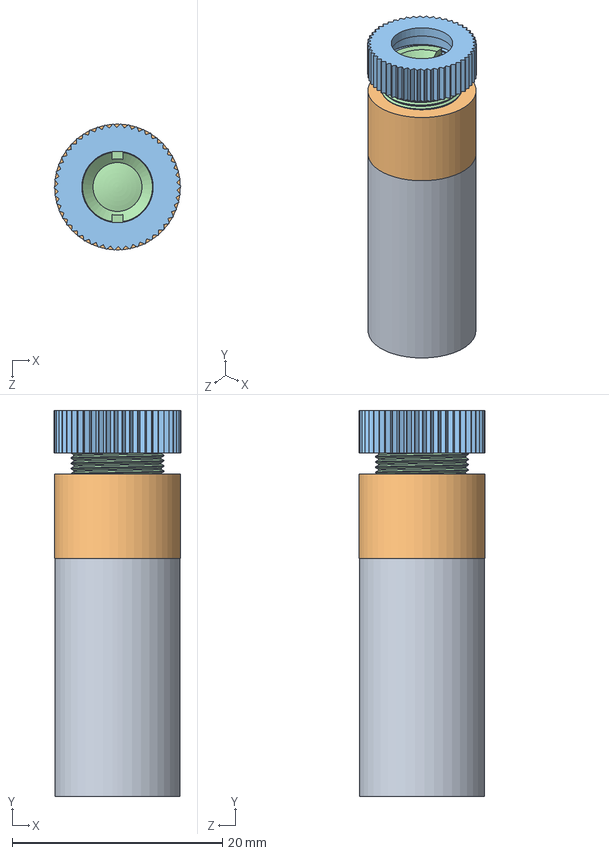
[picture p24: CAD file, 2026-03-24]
Model/Magisterka/aixiz-12mm-laser-diode-module-5-6mm-1.snapshot.1/Aixiz/Module Assembly.SLDASM
12.0 x 36.7 x 12.0 mm
Cap
Interface
Focus Ring
Acrylic Lens
TO-18 Laser Diode (M140)

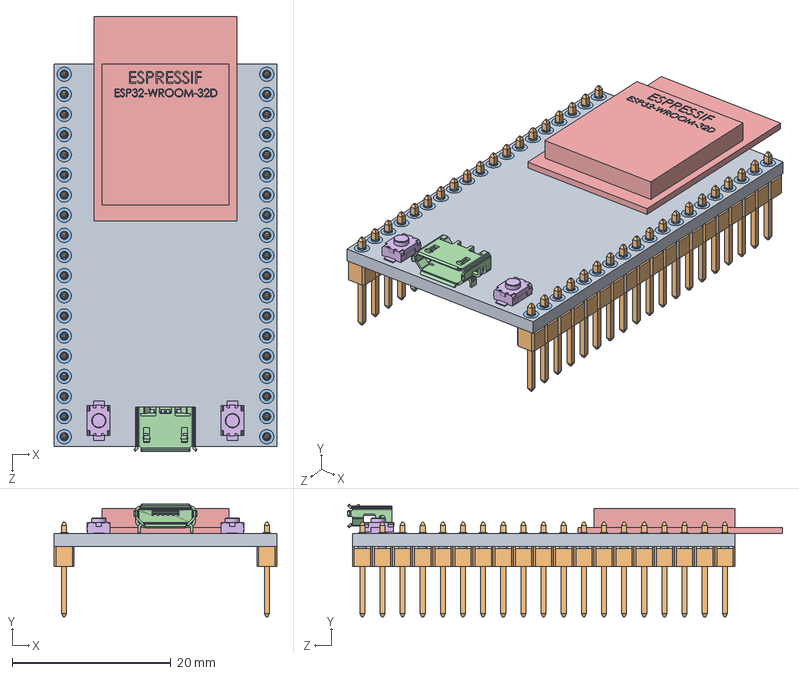
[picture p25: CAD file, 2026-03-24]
Model/Magisterka/esp32-devkitc-v4-1.snapshot.1/ESP-WROOM-32D-Export/ESP32-WROOM-32D-Assembly.SLDASM
28.1 x 14.2 x 54.9 mm
Main-PCB
zl201-19_p2-54_l48-3_w2-54_h8-9 x 2
Soldering-Contacts
ab2_usb_micro_smd.wrl
ESP32-chip
3x4x2mm_tact_button x 2

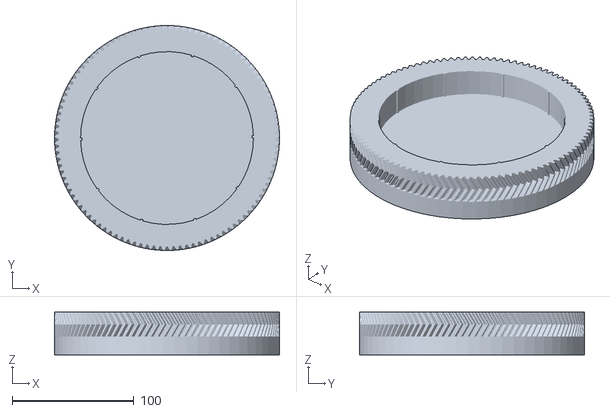
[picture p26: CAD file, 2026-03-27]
Color_detection_ros_Ubuntu/src/pan_tilt_description/meshes/base.stl
184.9 x 184.8 x 35.0

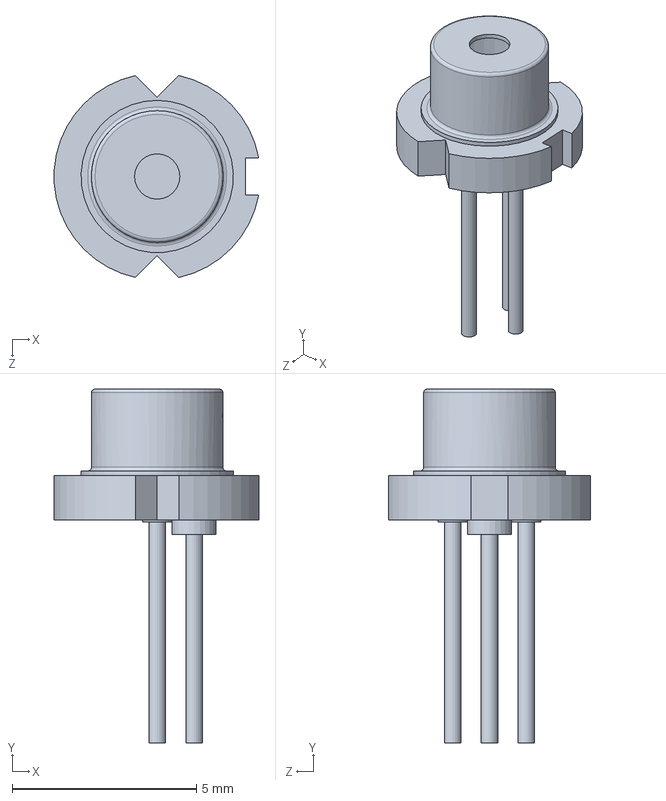
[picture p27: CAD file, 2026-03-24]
Model/Magisterka/aixiz-12mm-laser-diode-module-5-6mm-1.snapshot.1/Aixiz/TO-18 Laser Diode (M140).SLDPRT
5.55 x 9.60 x 5.48 mm

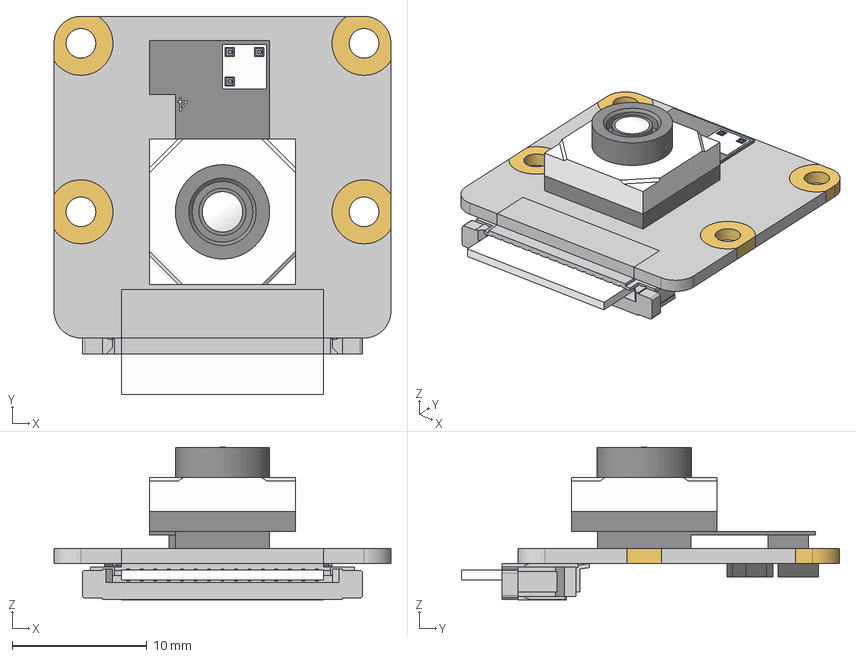
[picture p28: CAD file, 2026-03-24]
Model/Magisterka/raspberry-pi-camera-module-v3-2.snapshot.4/Camera Moudule 3 v8.step
25.0 x 28.1 x 11.3 mm
Board
sfw15r3ste1lf
Sensor
Lens
Ring
Mount
Housing

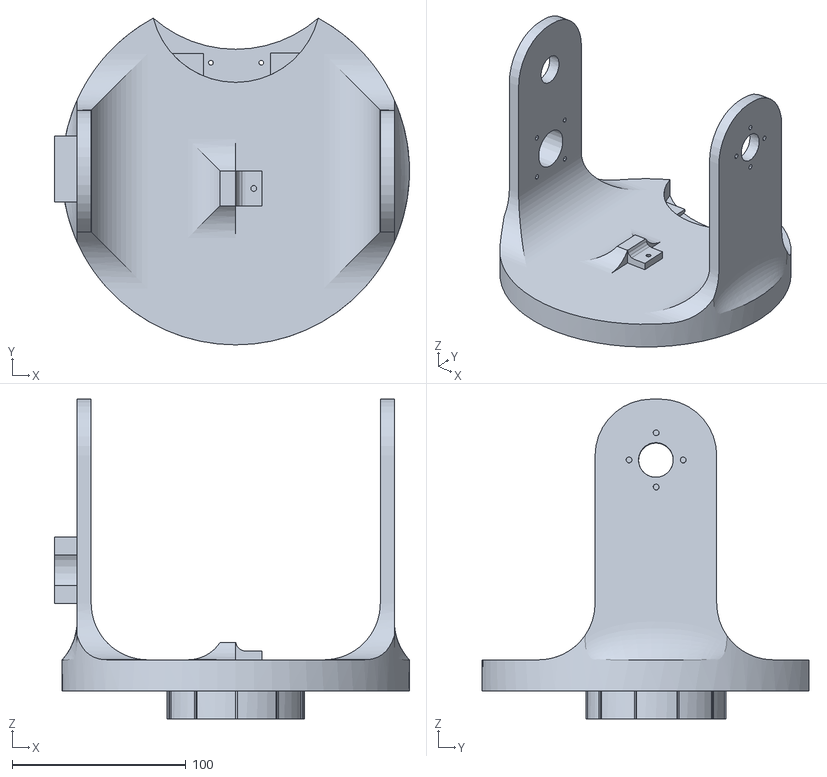
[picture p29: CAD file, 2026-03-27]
Color_detection_ros_Ubuntu/src/pan_tilt_description/meshes/pan_link.stl
204.3 x 188.0 x 184.0

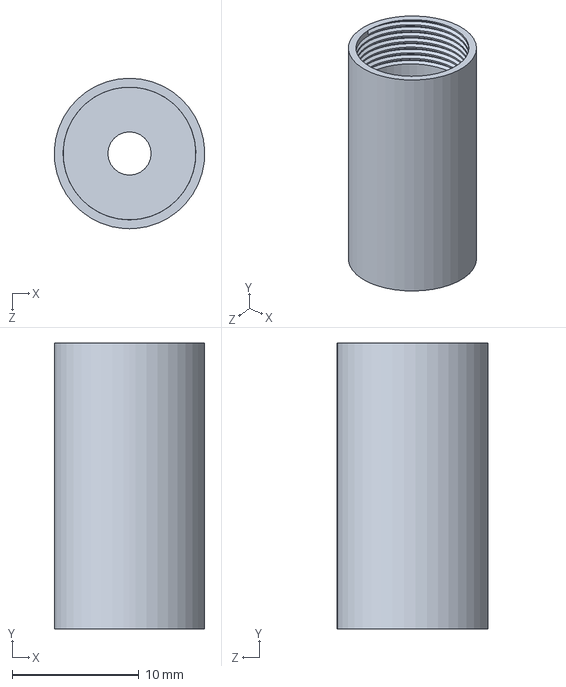
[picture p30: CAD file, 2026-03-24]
Model/Magisterka/aixiz-12mm-laser-diode-module-5-6mm-1.snapshot.1/Aixiz/Cap.SLDPRT
11.9 x 22.6 x 11.9 mm

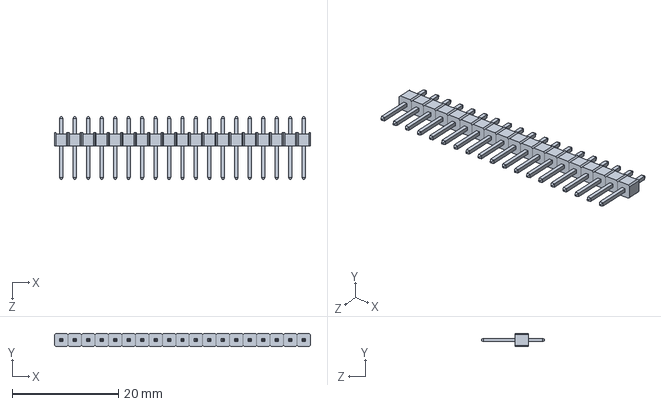
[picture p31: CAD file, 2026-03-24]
Model/Magisterka/esp32-devkitc-v4-1.snapshot.1/ESP-WROOM-32D-Export/zl201-19_p2-54_l48-3_w2-54_h8-9.SLDPRT
48.3 x 2.54 x 11.9 mm

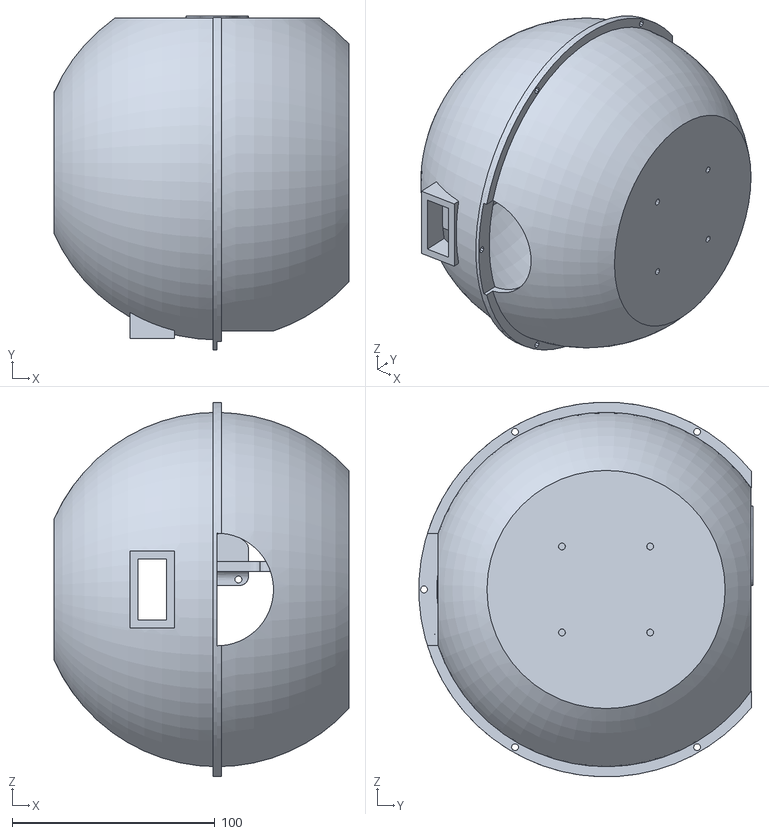
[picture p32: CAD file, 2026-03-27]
Color_detection_ros_Ubuntu/src/pan_tilt_description/meshes/tilt_link.stl
145.5 x 164.8 x 184.8

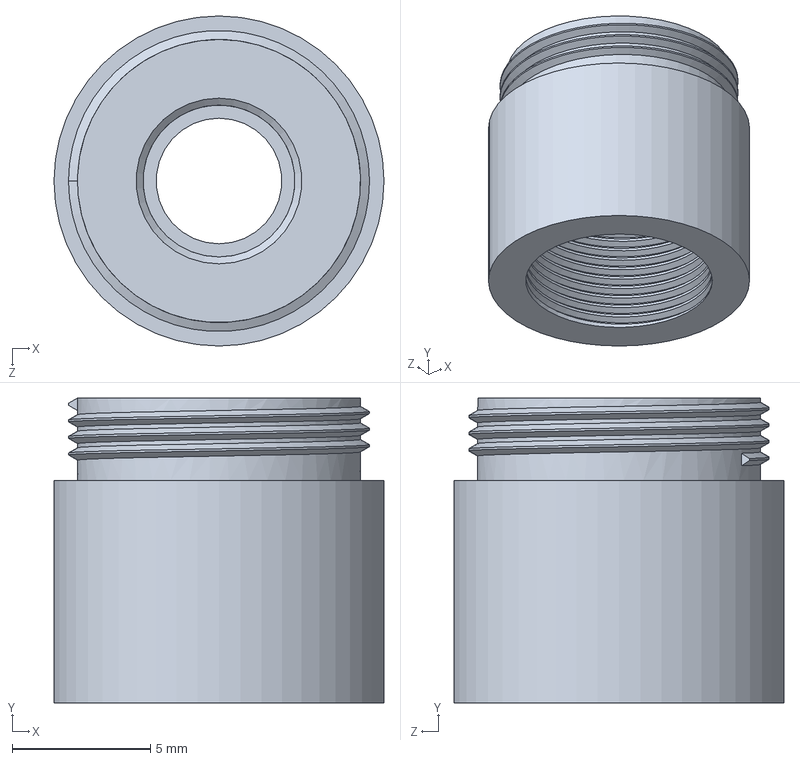
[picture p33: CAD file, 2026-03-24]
Model/Magisterka/aixiz-12mm-laser-diode-module-5-6mm-1.snapshot.1/Aixiz/Interface.SLDPRT
11.9 x 11.0 x 11.9 mm

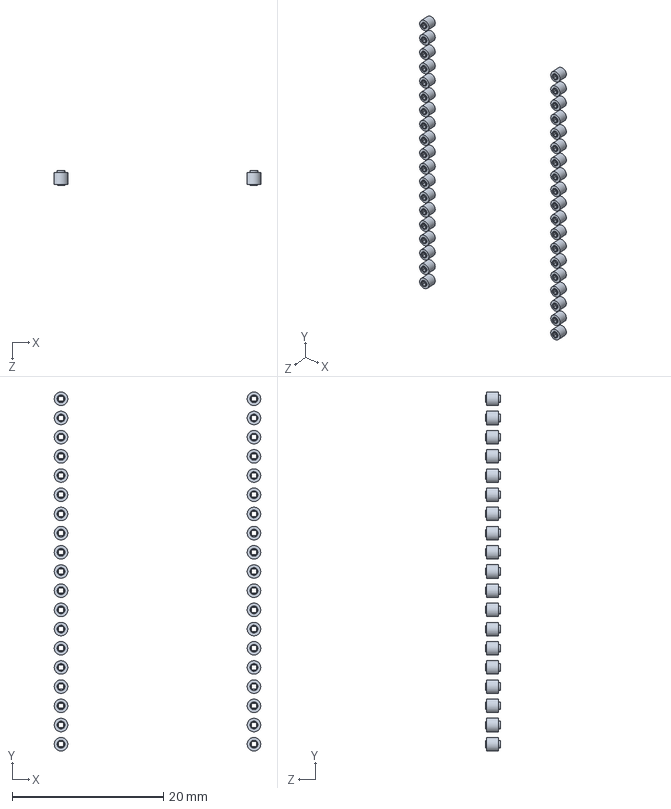
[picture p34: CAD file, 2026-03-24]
Model/Magisterka/esp32-devkitc-v4-1.snapshot.1/ESP-WROOM-32D-Export/Soldering-Contacts.SLDPRT
27.3 x 47.5 x 2.00 mm

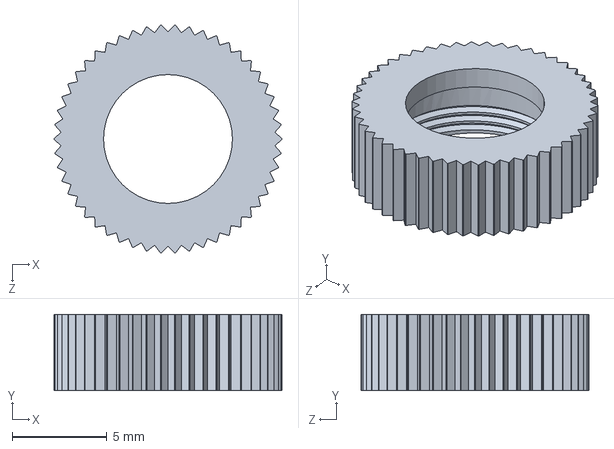
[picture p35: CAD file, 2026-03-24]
Model/Magisterka/aixiz-12mm-laser-diode-module-5-6mm-1.snapshot.1/Aixiz/Focus Ring.SLDPRT
12.0 x 4.02 x 12.0 mm

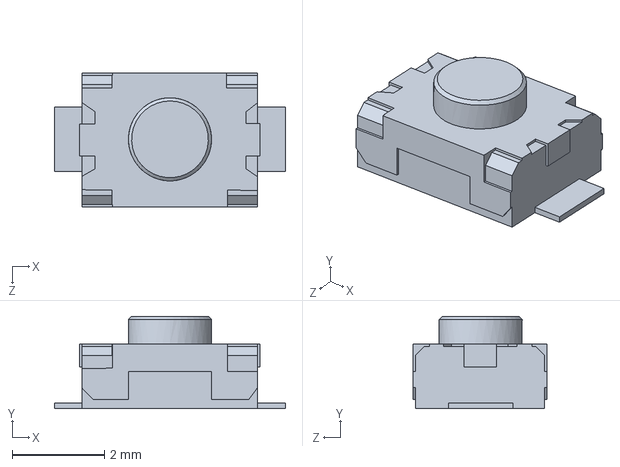
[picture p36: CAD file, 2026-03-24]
Model/Magisterka/esp32-devkitc-v4-1.snapshot.1/ESP-WROOM-32D-Export/3x4x2mm_tact_button.SLDPRT
5.00 x 2.00 x 2.90 mm

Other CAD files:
Model/Magisterka/aixiz-12mm-laser-diode-module-5-6mm-1.snapshot.1/Aixiz/Acrylic Lens.SLDPRT
Model/Magisterka/esp32-devkitc-v4-1.snapshot.1/ESP-WROOM-32D-Export/ab2_usb_micro_smd.wrl.SLDPRT
Model/Magisterka/esp32-devkitc-v4-1.snapshot.1/ESP-WROOM-32D-Export/ESP32-chip.SLDPRT
Model/Magisterka/18650-cell-holder-1.snapshot.1/18650 Cell Holder.step
Model/Gear.iam
Model/Gear/Design Accelerator/Gear 120.ipt
Model/Gear/Design Accelerator/Gear 30.ipt
Model/Gear/Design Accelerator/Gear 60.ipt
Model/Gear/Design Accelerator/OldVersions/Gear 30.0001.ipt
Model/Gear/Design Accelerator/OldVersions/Gear 60.0001.ipt
Model/Gear/Design Accelerator/Przekładnie walcowe1.iam
Model/Gear/Design Accelerator/Przekładnie walcowe2.iam
Model/Gear/Design Accelerator/Przekładnie walcowe3.iam
Model/Magisterka.iam
Model/Magisterka/18650-cell-holder-1.snapshot.1/18650 Cell Holder/18650 Cell Holder/18650 Cell Holder.ipt
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

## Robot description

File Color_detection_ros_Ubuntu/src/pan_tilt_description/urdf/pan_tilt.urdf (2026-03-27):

<?xml version="1.0"?>
<robot name="wiezyczka_pan_tilt">

  <link name="base_link">
    <visual>
      <origin xyz="0 0 0" rpy="0 0 0"/>
      <geometry>
        <mesh filename="package://pan_tilt_description/meshes/base.stl" />
      </geometry>
    </visual>
  </link>

  <joint name="pan_joint" type="revolute">
    <parent link="base_link"/>
    <child link="pan_link"/>
    <origin xyz="0 0 40" rpy="0 0 0"/> 
    <axis xyz="0 0 1"/> 
    <limit lower="-3.14" upper="3.14" effort="10.0" velocity="1.0"/>
  </joint>

  <link name="pan_link">
    <visual>
      <origin xyz="0 0 0" rpy="0 0 0"/>
      <geometry>
        <mesh filename="package://pan_tilt_description/meshes/pan_link.stl" />
      </geometry>
    </visual>
  </link>

  <joint name="tilt_joint" type="revolute">
    <parent link="pan_link"/>
    <child link="tilt_link"/>
    <origin xyz="10 0 120" rpy="0 0 3.14159"/> 
    <axis xyz="1 0 0"/> 
    <limit lower="-1.57" upper="1.57" effort="10.0" velocity="1.0"/>
  </joint>

  <link name="tilt_link">
    <visual>
      <origin xyz="0 0 0" rpy="0 0 0"/> 
      <geometry>
        <mesh filename="package://pan_tilt_description/meshes/tilt_link.stl" />
      </geometry>
    </visual>
  </link>

</robot>

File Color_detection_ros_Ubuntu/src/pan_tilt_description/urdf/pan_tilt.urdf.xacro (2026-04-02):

<?xml version="1.0"?>
<robot xmlns:xacro="http://www.ros.org/wiki/xacro" name="wiezyczka_pan_tilt">

  <link name="dummy_root"/>
  <joint name="fixed_to_dummy" type="fixed">
    <parent link="dummy_root"/>
    <child link="base_link"/>
  </joint>

  <xacro:macro name="dummy_inertia">
    <inertial>
      <mass value="0.1"/>
      <inertia ixx="0.001" ixy="0" ixz="0" iyy="0.001" iyz="0" izz="0.001"/>
    </inertial>
  </xacro:macro>

  <link name="base_link">
    <visual>
      <origin xyz="0 0 0" rpy="0 0 0"/>
      <geometry>
        <mesh filename="file://$(find pan_tilt_description)/meshes/base.stl" scale="0.001 0.001 0.001" />
      </geometry>
      <material name="gray"><color rgba="0.5 0.5 0.5 1.0"/></material>
    </visual>
    <collision>
      <geometry><box size="0.1 0.1 0.1"/></geometry>
    </collision>
    <xacro:dummy_inertia/>
  </link>

  <joint name="pan_joint" type="revolute">
    <parent link="base_link"/>
    <child link="pan_link"/>
    <origin xyz="0 0 0.04" rpy="0 0 0"/> 
    <axis xyz="0 0 1"/> 
    <limit lower="-3.14" upper="3.14" effort="10.0" velocity="1.0"/>
    <dynamics damping="1.0" friction="1.0"/> </joint>

  <link name="pan_link">
    <visual>
      <origin xyz="0 0 0" rpy="0 0 0"/>
      <geometry>
        <mesh filename="file://$(find pan_tilt_description)/meshes/pan_link.stl" scale="0.001 0.001 0.001" />
      </geometry>
      <material name="dark_gray"><color rgba="0.3 0.3 0.3 1.0"/></material>
    </visual>
    <collision>
      <geometry><cylinder radius="0.05" length="0.1"/></geometry>
    </collision>
    <xacro:dummy_inertia/>
  </link>

  <joint name="tilt_joint" type="revolute">
    <parent link="pan_link"/>
    <child link="tilt_link"/>
    <origin xyz="0.01 0 0.12" rpy="0 0 3.14159"/> 
    <axis xyz="1 0 0"/> 
    <limit lower="-1.57" upper="1.57" effort="10.0" velocity="1.0"/>
    <dynamics damping="1.0" friction="1.0"/> </joint>

  <link name="tilt_link">
    <visual>
      <origin xyz="0 0 0" rpy="0 0 0"/> 
      <geometry>
        <mesh filename="file://$(find pan_tilt_description)/meshes/tilt_link.stl" scale="0.001 0.001 0.001" />
      </geometry>
      <material name="dark_gray"><color rgba="0.3 0.3 0.3 1.0"/></material>
    </visual>
    <collision>
      <geometry><cylinder radius="0.05" length="0.1"/></geometry>
    </collision>
    <xacro:dummy_inertia/>
  </link>

  <joint name="camera_joint" type="fixed">
    <origin xyz="0.01 0.08 0" rpy="0 0 1.57075"/>
    <parent link="tilt_link"/>
    <child link="camera_link"/>
  </joint>

  <link name="camera_link">
    <visual>
      <geometry>
        <box size="0.02 0.05 0.05"/>
      </geometry>
      <material name="red"><color rgba="1.0 0.0 0.0 1.0"/></material>
    </visual>
    <inertial>
      <mass value="0.0001"/>
      <inertia ixx="0.000001" ixy="0" ixz="0" iyy="0.000001" iyz="0" izz="0.000001"/>
    </inertial>
  </link>

  <gazebo reference="camera_joint">
    <disableFixedJointLumping>true</disableFixedJointLumping>
  </gazebo>

  <gazebo reference="base_link">
    <material>Gazebo/Grey</material>
  </gazebo>
  <gazebo reference="pan_link">
    <material>Gazebo/DarkGrey</material>
  </gazebo>
  <gazebo reference="tilt_link">
    <material>Gazebo/DarkGrey</material>
  </gazebo>

  <gazebo reference="camera_link">
    <material>Gazebo/Red</material>
    <sensor name="main_camera" type="camera">
      <camera>
        <horizontal_fov>1.396</horizontal_fov>
        <image>
          <width>640</width>
          <height>480</height>
          <format>R8G8B8</format>
        </image>
        <clip>
          <near>0.02</near>
          <far>100.0</far>
        </clip>
      </camera>
      <always_on>1</always_on>
      <update_rate>30</update_rate>
      <visualize>true</visualize>
      <topic>camera/image_raw</topic>
    </sensor>
  </gazebo>

  <gazebo>
    <plugin filename="libignition-gazebo-joint-position-controller-system.so" name="ignition::gazebo::systems::JointPositionController">
      <joint_name>pan_joint</joint_name>
      <topic>model/pan_tilt_turret/joint/pan_joint/cmd_pos</topic>
      <p_gain>5.0</p_gain>
      <i_gain>0.1</i_gain>
      <d_gain>0.5</d_gain>
    </plugin>
  </gazebo>

  <gazebo>
    <plugin filename="libignition-gazebo-joint-position-controller-system.so" name="ignition::gazebo::systems::JointPositionController">
      <joint_name>tilt_joint</joint_name>
      <topic>model/pan_tilt_turret/joint/tilt_joint/cmd_pos</topic>
      <p_gain>5.0</p_gain>
      <i_gain>0.1</i_gain>
      <d_gain>0.5</d_gain>
    </plugin>
  </gazebo>

</robot>

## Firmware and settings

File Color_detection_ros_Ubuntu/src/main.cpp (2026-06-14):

#include <Arduino.h>
#include <SPI.h>
#include <HighPowerStepperDriver.h>
#include <WiFi.h>
#include <WiFiMulti.h>
#include <ESPmDNS.h>
#include <WiFiUdp.h>
#include <ArduinoOTA.h>
#include <AccelStepper.h>

WiFiMulti wifiMulti;


const float KROKI_NA_OBROT = 200.0; 
const float MIKROKROK = 8.0;        
const int LIMIT_PRADU_MA = 1000;


const float PRZELOZENIE_PAN = 105.0 / 20.0;
const float PRZELOZENIE_TILT = 38.0 / 24.0;

long obliczKrokiPan(float stopnie) {
  return (stopnie / 360.0) * KROKI_NA_OBROT * MIKROKROK * PRZELOZENIE_PAN;
}

long obliczKrokiTilt(float stopnie) {
  return (stopnie / 360.0) * KROKI_NA_OBROT * MIKROKROK * PRZELOZENIE_TILT;
}

HighPowerStepperDriver sd1; // PAN 
HighPowerStepperDriver sd2; // TILT 

// Piny PAN
const uint8_t SCS1_PIN = 5;
const uint8_t STEP1_PIN = 16;
const uint8_t DIR1_PIN = 4;

// Piny TILT
const uint8_t SCS2_PIN = 17;
const uint8_t STEP2_PIN = 12;
const uint8_t DIR2_PIN = 14;

// Laser
const uint8_t LASER_PIN = 25;


AccelStepper stepperPan(AccelStepper::DRIVER, STEP1_PIN, DIR1_PIN);
AccelStepper stepperTilt(AccelStepper::DRIVER, STEP2_PIN, DIR2_PIN);

String commandBuffer = "";

void setup() {
  Serial.begin(115200);
  SPI.begin(); 
  
  pinMode(LASER_PIN, OUTPUT);
  digitalWrite(LASER_PIN, LOW);

  Serial.println("\nKonfiguracja Wi-Fi...");
  wifiMulti.addAP("xxx", "yyy");


  int attempts = 0;
  while (wifiMulti.run() != WL_CONNECTED && attempts < 10) {
    delay(1000);
    Serial.print(".");
    attempts++;
  }

  if(WiFi.status() == WL_CONNECTED) {
    Serial.println("\n--- POLACZONO Z WI-FI! ---");
    Serial.print("Adres IP urzadzenia: "); Serial.println(WiFi.localIP());
  }

  if(WiFi.status() == WL_CONNECTED) {
    ArduinoOTA.setHostname("Wiezyczka-Laserowa");
    ArduinoOTA.begin();
  }

  sd1.setChipSelectPin(SCS1_PIN);
  sd1.resetSettings();
  sd1.clearStatus();
  sd1.setCurrentMilliamps36v4(LIMIT_PRADU_MA); 
  sd1.setStepMode(HPSDStepMode::MicroStep8); 
  sd1.enableDriver(); 

  sd2.setChipSelectPin(SCS2_PIN);
  sd2.resetSettings();
  sd2.clearStatus();
  sd2.setCurrentMilliamps36v4(LIMIT_PRADU_MA); 
  sd2.setStepMode(HPSDStepMode::MicroStep8); 
  sd2.enableDriver(); 

  stepperPan.setMaxSpeed(8000.0);     
  stepperPan.setAcceleration(6000.0); 
  
  stepperTilt.setMaxSpeed(4000.0);    
  stepperTilt.setAcceleration(3000.0);

  Serial.println("==========================================");
  Serial.println("Ready");
  Serial.println("==========================================");
}


void loop() {
  ArduinoOTA.handle();

  stepperPan.run();
  stepperTilt.run();

  while (Serial.available() > 0) {
    char c = Serial.read();
    
    if (c == '\n') {
      if (commandBuffer.length() > 2) {
        int pierwszaSpacja = commandBuffer.indexOf(' ');
        int drugaSpacja = commandBuffer.indexOf(' ', pierwszaSpacja + 1);
        
        if (pierwszaSpacja > 0 && drugaSpacja > 0) {
          float docelowyKatPan = commandBuffer.substring(0, pierwszaSpacja).toFloat();
          float docelowyKatTilt = commandBuffer.substring(pierwszaSpacja + 1, drugaSpacja).toFloat();
          int stanLasera = commandBuffer.substring(drugaSpacja + 1).toInt();

          docelowyKatTilt = constrain(docelowyKatTilt, -35.0, 35.0);

          digitalWrite(LASER_PIN, (stanLasera == 1) ? HIGH : LOW);

          long celPan = obliczKrokiPan(docelowyKatPan);
          long celTilt = obliczKrokiTilt(docelowyKatTilt);

          stepperPan.moveTo(celPan);
          stepperTilt.moveTo(celTilt);
        }
      }
      commandBuffer = "";
    } else {
      commandBuffer += c;
    }
    
    stepperPan.run();
    stepperTilt.run();
  }
}

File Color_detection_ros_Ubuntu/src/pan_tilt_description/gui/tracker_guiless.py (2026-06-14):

#!/usr/bin/env python3
import cv2
import numpy as np
import serial
import time
import threading
import csv
import datetime
# (self, kp=0.005, ki=0.0, kd=0.0001):
    # (self, kp=0.084, ki=0.0, kd=0.0063):
    # (self, kp=0.067, ki=0.0, kd=0.011):
    # (self, kp=0.021, ki=0.0, kd=0.0136):
class SimplePID:
    def __init__(self, kp=0.058, ki=0.0, kd=0.0019):
        self.kp = kp
        self.ki = ki
        self.kd = kd
        self.integral = 0.0
        self.prev_error = 0.0
        self.prev_derivative = 0.0

    def compute(self, error, dt):
        if dt <= 0: return 0.0
        
        self.integral += error * dt
        
        raw_derivative = (error - self.prev_error) / dt
        self.prev_error = error
        
        alpha = 0.3 
        filtered_derivative = (alpha * raw_derivative) + ((1.0 - alpha) * self.prev_derivative)
        self.prev_derivative = filtered_derivative

        output = (self.kp * error) + (self.ki * self.integral) + (self.kd * filtered_derivative)
        
        limit = 1.5 
        if output > limit: output = limit
        elif output < -limit: output = -limit
        
        return output

    def set_params(self, kp, ki, kd):
        self.kp = kp
        self.ki = ki
        self.kd = kd
        self.integral = 0.0

class HeadlessTurretTracker:
    def __init__(self):
        try:
            self.ser = serial.Serial('/dev/ttyUSB0', 115200, timeout=0.05)
            time.sleep(2)
        except Exception:
            self.ser = None
            print("[OSTRZEŻENIE] Nie wykryto połączenia z ESP32 (ttyUSB0).")

        self.latest_frame = None
        self.running = True

        self.cap = cv2.VideoCapture(0)
        self.cap.set(cv2.CAP_PROP_FRAME_WIDTH, 640)
        self.cap.set(cv2.CAP_PROP_FRAME_HEIGHT, 480)
        self.cap.set(cv2.CAP_PROP_FPS, 30)
        self.cap.set(cv2.CAP_PROP_BUFFERSIZE, 1)

        threading.Thread(target=self.grab_frames, daemon=True).start()
        threading.Thread(target=self.terminal_listener, daemon=True).start()

        self.mode = "AUTO"
        self.ctrl_type = "PID"
        self.state = "SEARCHING"
        self.target_hsv = np.array([0, 220, 180], dtype=np.uint8)
        self.pid_pan = SimplePID(kp=0.058, ki=0.0, kd=0.0019)
        self.pid_tilt = SimplePID(kp=0.058, ki=0.0, kd=0.0019)
        self.pan_enabled = True
        self.tilt_enabled = True
        self.current_pan = 0.0
        self.current_tilt = 0.0
        self.laser_state = 0
        self.last_sent_pan = -999.0
        self.last_sent_tilt = -999.0
        self.last_sent_laser = -1
        self.prev_gray = None
        self.roi_rect = None
        self.lost_time = 0.0
        
        self.logging_started = False
        self.log_file = None
        self.csv_writer = None
        self.start_log_time = 0.0
        
        self.do_probe = False
        
        self.reset_kalman()
        self.frame_count = 0
        self.fps_timer = time.time()
        self.fps_filtered = 0.0
        self.last_time = time.time()
        print("\n[SYSTEM] Tracker Headless zainicjowany pomyślnie.")

    def reset_kalman(self):
        self.kalman = cv2.KalmanFilter(4, 2)
        self.kalman.measurementMatrix = np.array([[1,0,0,0],[0,1,0,0]], np.float32)
        self.kalman.transitionMatrix = np.array([[1,0,1,0],
                                                 [0,1,0,1],
                                                 [0,0,1,0],
                                                 [0,0,0,1]], np.float32)

        self.kalman.processNoiseCov = np.eye(4, dtype=np.float32) * 0.003
        self.kalman.measurementNoiseCov = np.eye(2, dtype=np.float32) * 5.0

    def grab_frames(self):
        while self.running:
            ret, frame = self.cap.read()
            if ret: 
                self.latest_frame = frame
            else: 
                time.sleep(0.01)

    def classify_color_hsv(self, h, s, v):
        """Klasyfikacja barwy na podstawie przestrzeni HSV."""
        if v < 40: return "Czarny / Ciemny"
        if s < 30 and v > 200: return "Biały"
        if s < 40: return "Szary"

        if h < 10 or h > 165: return "Czerwony"
        elif h < 22: return "Pomarańczowy"
        elif h < 35: return "Żółty"
        elif h < 85: return "Zielony"
        elif h < 110: return "Błękitny (Cyjan)"
        elif h < 135: return "Niebieski"
        elif h < 165: return "Fioletowy / Różowy"
        return "Nieokreślony"

    def terminal_listener(self):
        print("\n=== KONSOLA STEROWANIA (Wpisz 'help' aby zobaczyć komendy) ===")
        while self.running:
            try:
                cmd_line = input("> ").strip().lower().split()
                if not cmd_line:
                    continue
                
                cmd = cmd_line[0]

                if cmd == "help":
                    print("\n--- DOSTĘPNE KOMENDY ---")
                    print("  mode auto     - Przełącza na śledzenie autonomiczne")
                    print("  mode manual   - Przełącza na sterowanie ręczne")
                    print("  ctrl pid      - Zmienia algorytm na regulator PID")
                    print("  ctrl bang     - Zmienia algorytm na trójpołożeniowy (Bang-Bang)")
                    print("  move P T L    - Ruch ręczny (np: move 15 -10 1) [Pan, Tilt, Laser]")
                    print("  color H S V   - Ręczna nastawa koloru HSV (np: color 25 200 200)")
                    print("  probe         - PIPETA: Zczytuje kolor ze środka kadru kamery")
                    print("  log start     - Rozpoczyna zapis danych uchybu do pliku CSV")
                    print("  log stop      - Kończy i zapisuje plik CSV")
                    print("  quit / exit   - Bezpieczne zamknięcie programu\n")
                    
                elif cmd == "mode":
                    if len(cmd_line) > 1 and cmd_line[1] in ["auto", "manual"]:
                        self.mode = cmd_line[1].upper()
                        print(f"[SYSTEM] Zmieniono tryb na: {self.mode}")
                    else:
                        print("Użycie: mode auto | mode manual")
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

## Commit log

2026-03-24 Added models and literature
    [18650 Cell Holder.ipt, 18650 Cell Holder.step, 3x4x2mm_tact_button.SLDPRT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]
2026-03-27 Dodanie środowiska ROS 2 do detekcji koloru i ROI (Docker + OpenCV)
    [base.stl, pan_link.stl, pan_tilt.urdf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]
2026-04-02 Adding full simulation and pid autotune
    [pan_tilt.urdf.xacro, target_world.sdf]
2026-05-07 Added platformio backup
    [target_world.sdf]
2026-05-07 README fix
    Add SSH login information and launch instructions for Raspberry Pi and Ubuntu.
2026-05-15 Refactor WiFi and motor configuration in main.cpp
2026-05-15 Refactor turret GUI layout and socket configuration
2026-05-15 Refactor PID auto-tuning logic
2026-05-17 Fixed turret setting and adding plot
    [data.csv]
2026-05-18 Add sound device to Docker run command
2026-05-18 Fixing regulator
    [data.csv]
2026-06-01 Chapter 3 ongoing
    [test1.kicad_pcb, test1.kicad_sch]
2026-06-02 Chapter 5 and problems with undervolting
    [data.csv]
2026-06-03 Fixed undervolting problem
    [PID_LP.csv, PID_up.csv, bang_LP.csv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]
2026-06-05 Added figures and research
    [A_Modelnercyjny copy.csv, A_Modelnercyjny.csv, A_Skok.csv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]
2026-06-07 Terrain experiment and kicad files
    [A_Terrain_BB_LP.csv, A_Terrain_PID_lp.csv]
2026-06-08 Fixes and sumarise
    [UP_BB_circural_150_cm.csv, UP_BB_circural_30_cm.csv, UP_BB_circural_80_cm.csv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]
